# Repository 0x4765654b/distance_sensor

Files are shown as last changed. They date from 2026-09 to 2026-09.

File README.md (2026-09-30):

# SaltMon — Water-Softener Salt Level Monitor

SaltMon watches the salt tank of a Culligan Gold Series water softener. A US-100 ultrasonic sensor, mounted under
the tank lid, measures the distance down to the salt. An ESP32-C6 in a wall-mounted box turns that distance into a
salt level. It shows the level on lid LEDs and publishes readings to AWS IoT Core. A SaltMon AWS stack stores the
history, forecasts when the salt will run out, and publishes the results over SNS. There, the ChoreCore household
app picks them up and creates an "Add salt" chore.

**Status:** design phase. The requirements, the carrier schematic and the routed carrier PCB are done. Firmware,
the cloud stack and the tooling are not started yet.

## Repository Layout

```
docs/                     requirements, pin map, integration contract, pick list, datasheets
kicad/lib/                ESP32-C6-DevKitM-1 symbol + socketed footprint (generated)
kicad/DepthSensor/        carrier PCB project (KiCad 10): schematic, board, Gerbers, generator scripts
models/                   ESP32-S3 dev-kit library (not used; kept for reference)
firmware/                 ESP-IDF application                      (planned)
cloud/                    SaltMon-<env> CDK stack + Lambdas        (planned)
tools/                    provision.py, saltmon-config.py          (planned)
```

## Documents

| Document | Contents |
|---|---|
| [docs/requirements.md](docs/requirements.md) | System requirements: design decisions, parts, power, LEDs, sensor, firmware, cloud, mechanics, verification |
| [docs/pinmap.md](docs/pinmap.md) | Kit header pads, carrier connectors, U2 pinout. Source of truth for firmware `board.h` |
| [docs/integration-contract.md](docs/integration-contract.md) | SNS message contract between SaltMon and its consumers (ChoreCore) |
| [docs/pick-list.md](docs/pick-list.md) | Everything to buy or gather for one build (carrier, cables, enclosure) |
| [docs/lid-pick-list.md](docs/lid-pick-list.md) | The lid panel board: parts, LED spacers, mounting hardware, assembly order |

## Hardware

- **Carrier PCB:** 80.5 × 92 mm, 2-layer, all through-hole. The ESP32-C6-DevKitM-1 plugs into female headers.
  The board also carries a TBD62783APG LED driver, the power path (fuse, lid switch loop, Schottky diode), the
  sensor-line filters, and keyed headers for the lid ribbon (J_PANEL) and the sensor ribbon (J_SNS).
- **Lid panel PCB:** 50 × 63 mm, passive, on standoffs behind the lid. It holds 8 flat-top LEDs (salt level,
  network, activity, power) and pads for the panel-mounted on/off slide switch and push-button. A 16-way ribbon
  with an IDC socket at each end connects it 1:1 to the carrier. The same KiCad file carries the 1:1 lid drilling
  template on User.Drawings. What each LED shows is in requirements §5.4.
- **Sensor:** a US-100 in UART mode on a 6-way ribbon, about 1.2 m long.
- **Enclosure:** a gasketed ABS junction box, wall-mounted through its 4 corner holes.

Gerbers for fabrication are in `kicad/DepthSensor/depth_gerber/` (also zipped as `depth_gerber.zip`).

### Regenerating the Schematic and PCB

The schematic, the kit footprint and the PCB are all generated by scripts. Change the script, not the KiCad file,
then regenerate:

```sh
KICAD=/Applications/KiCad/KiCad.app/Contents
KPY=$KICAD/Frameworks/Python.framework/Versions/Current/bin/python3   # KiCad's Python (has pcbnew)
CLI=$KICAD/MacOS/kicad-cli

python3 kicad/lib/gen_devkit.py                    # kit symbol + footprint
python3 kicad/DepthSensor/gen_schematic.py         # schematic (deterministic UUIDs)
$CLI sch erc kicad/DepthSensor/DepthSensor.kicad_sch

$KPY kicad/DepthSensor/gen_pcb.py                  # place, autoroute (Freerouting), pour GND
$KPY kicad/DepthSensor/gen_pcb.py --no-route       # placement only
$CLI pcb drc --schematic-parity kicad/DepthSensor/DepthSensor.kicad_pcb

python3 kicad/LidPanel/gen_schematic.py           # lid panel: same steps
$KPY kicad/LidPanel/gen_pcb.py
$CLI pcb drc --schematic-parity kicad/LidPanel/LidPanel.kicad_pcb
$CLI pcb export pdf --mode-single -l User.Drawings --scale 1 -o lid-template.pdf kicad/LidPanel/LidPanel.kicad_pcb
```

Helpers shared by both boards are in `kicad/lib/schgen.py` (schematic) and `kicad/lib/pcbgen.py` (PCB).

`gen_pcb.py` needs Java 21+ and the Freerouting jar at `kicad/freerouting/freerouting-*.jar`. The jar is not in git;
download it from the [Freerouting releases](https://github.com/freerouting/freerouting/releases). It was tested
with 2.4.1. Close the board in KiCad before regenerating, and re-export the Gerbers afterwards.

## License

[MIT](LICENSE)

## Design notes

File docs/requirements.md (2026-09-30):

# Salt Level Monitor — System Requirements

Status: **DRAFT v0.8** (2026-09-30) — design phase. Covers the hardware (carrier PCB + passive lid panel PCB), device firmware, the `SaltMon` AWS stack, and the ChoreCore consumer contract. Open items are in [§12](#12-open-questions).

Reference docs in `docs/`:
- `4019_Web.pdf` — Adafruit US-100
- `esp32-c6-devkitm-1-schematics.pdf`, `-dimensions.pdf`, `-dimensions.dxf` — ESP32-C6-DevKitM-1 v1.0
- Culligan Gold Series Owner's Guide (P/N 01018854): <https://www.culligan.com/wp-content/uploads/2019/07pdf/Gold_Softener_01018854.pdf>
- `esp-dev-kits-en-master-esp32s3.pdf`, `models/ESP32_S3_DEVKITM_1_N8/` — **not used** (D-02)

### Proposed repository layout

```
docs/       requirements, pin map, ICDs, datasheets
kicad/      DepthSensor carrier PCB (KiCad 10)
firmware/   ESP-IDF v5.x application
cloud/      SaltMon-<env> CDK stack (TypeScript) + Python Lambdas
tools/      provision.py, saltmon-config.py
```

The ChoreCore consumer feature lives in `~/github/chorecore` (§8.7).

---

## 1. Product Summary

A monitor for the salt tank of a **Culligan Gold Series (9" media tank)** water softener.
A US-100 ultrasonic sensor mounted **on the underside of the salt tank lid** looks down at
the salt. It connects over a ribbon cable to a **wall-mounted enclosure** nearby. The enclosure
holds an ESP32-C6, which works out the salt level, shows it on the lid LEDs, and publishes
readings to **AWS IoT Core**. A **SaltMon** AWS stack in this repo stores the history, forecasts
when salt will run out, and publishes the results. The **ChoreCore** household app consumes them and creates an "Add salt" chore when it is time.

### 1.1 Salt Tank & Installation Geometry

From the Culligan Gold Series specification: the user's **375 lb** salt tank is **18 in dia × 43 in** (45.7 × 109 cm). It has a salt support plate, a Dubl-Safe brine valve inside a brine chamber tube at the side of the tank, and water kept about 1 in above the support plate. Culligan says to fill salt "to within a few inches of the top".

```
     wall-mounted enclosure                    salt tank lid (removable for refills)
   ┌───────────────────┐                  ┌───────────────────────────────┐
   │ LEDs, switch, btn │   ribbon cable   │  ▼▼ US-100 on underside       │
   │  (front panel)    │══════════════════╪══╝  offset away from brine    │
   │  [carrier + ESP32]│  (~1.2 m, slack  │      chamber                  │
   └───┬───┬───┬───────┘   for lid lift)  │                               │
      jack USB cable                      │   d ≈ 8–15 cm   salt, full    │ ║ brine
                                          │                               │ ║ chamber
                                          │   15° beam                    │ ║ tube
                                          │   d_low         refill point  │ ║
                                          │   ~~~ water ~1 in above plate │ ║
                                          │ ═══ salt support plate ═══    │ ║
                                          └───────────────────────────────┘
                                             109 cm (43 in) tall, 45.7 cm dia
```

| ID | Requirement |
|---|---|
| GEO-01 | Measurement range 5–110 cm. The US-100 is specified for 2–450 cm (best 10–250 cm). Accuracy ±(0.3 cm + 1%). |
| GEO-02 | Mount the sensor on the lid underside with the transducers pointing straight down, **3–5 cm off the tank center, on the side away from the brine chamber**. The beam footprint radius is about 0.13 × depth (≈ 14 cm at the plate). The tank radius is 22.9 cm, so the brine-chamber tube and the walls stay out of the beam down to the plate. |
| GEO-03 | Readings < 50 mm → `OBSTRUCTED` (salt piled against the sensor, or the lid is off and something is in front of it). |
| GEO-04 | The salt support plate is **1 in (25 mm) above the tank floor**, and the water sits about 1 in above the plate. Measured from the lid underside (≈ tank top, 1092 mm), that puts the plate at about 1067 mm and the water at about 1041 mm. Defaults until calibrated: `d_full` = 150 mm (salt a few inches below the top), **`d_low` = 900 mm** (salt ≈ 5½ in above the water ≈ 55 lb left, enough for a few regenerations). At install, record the real `d_plate` with the tank low and set `d_low` = `d_plate` − 170 mm. |
| GEO-05 | **Salt mass estimate (cloud):** 18 in dia → 254 in² of cross-section. At a salt bulk density of about 70 lb/ft³ (configurable), that is about **10.3 lb per inch** of salt height (≈ 4.1 lb/cm). A 40 lb bag raises the level by about 4 in. |
| GEO-06 | The lid is lifted at every refill. The cable needs enough slack and strain relief at both ends, and it unplugs at the sensor end. |

### 1.2 System Block Diagram

```
 ┌──────────────────────────── Carrier PCB (enclosure floor) ─────────────────────────────┐
 │ J1 jack ─► F1 PTC ─► (J_PANEL: lid switch)  ─► D1 Schottky ─► V_SYS ~4.6 V             │
 │                                                                  │                      │
 │  ESP32-C6-DevKitM-1 (socketed) ◄── 5V pin ───────────────────────┤                      │
 │     3V3 ─────────────────────────────────► J_SNS (2×3 IDC) ══ ribbon ══► US-100 (lid)   │
 │     GPIO22/23 UART1 ─── 100 Ω ───────────► J_SNS                                        │
 │     GPIO ×8 ─► U2 TBD62783APG ─► R ×8 ───► J_PANEL (2×8 IDC)                            │
 │     GPIO19 ◄── button ───────────────────── J_PANEL                                     │
 │  V_SYS ─► R_PWR ─────────────────────────► J_PANEL                                      │
 └────────────────────────────────────────────────────╥────────────────────────────────────┘
                                                      ║ 16-way IDC ribbon, ~20 cm, IDC socket each end, 1:1
 ┌──────────── Lid panel PCB (behind the lid) ────────╨───────────┐
 │  8 × 5 mm flat-top LEDs · pads for panel switch + push-button  │
 └────────────────────────────────────────────────────────────────┘
       Wi-Fi 2.4 GHz ─► router ─► AWS IoT Core ─► SaltMon stack (ingest · history · forecast) ─► SNS ─► ChoreCore (chore · reminders · UI)
```

---

## 2. Design Decisions Log

| ID | Decision | Rationale |
|---|---|---|
| D-01 | Monitor the salt level for a Culligan Gold Series (9") softener. | User |
| D-02 | ESP32-C6-DevKitM-1. | User |
| D-03 | Barrel jack on the carrier PCB. Power switch on the housing. | User |
| D-04 | All through-hole parts. Dev kit and US-100 are removable (they plug into headers). | User |
| D-05 | The US-100 sits **on the underside of the tank lid, connected by ribbon cable**. The enclosure is **wall-mounted** nearby. | User. The enclosure no longer has to sit on the tank. |
| D-06 | Enclosure: user's unlabeled **ABS gasketed junction box**, about 4.5 × 3.5 × 2 in (≈ 115 × 90 × 55 mm class). It has a deep base, a tray-style lid, brass inserts at the corners, and PCB bosses in the floor (§9). The RadioShack 270-1801 is rejected. | Fits the carrier + kit + lid wiring with margin. The gasket helps in a humid utility room. |
| D-07 | LED driver: TBD62783APG (8-ch source driver). All cathodes go to GND. | Through-hole; 3.3 V inputs; suits the common-cathode bi-color LED. |
| D-08 | White power LED is hard-wired to V_SYS. | "Power stays on dimly" |
| D-09 | Separate indicators for network status (bi-color), network activity (Blue), and sensor activity (Purple). | User |
| D-10 | **Lid panel PCB** (`kicad/LidPanel`, 50 × 63 mm, passive) on standoffs behind the lid. It holds the 8 flat-top LEDs, solder pads for the panel-mounted switch and button, and J_LID, a right-angle 2×8 shrouded header wired 1:1 to J_PANEL. The resistors, driver and pull-up stay on the carrier. The switch and button stay panel-mounted so the lid seals. | Replaces the hand-wired lid (v0.7): no fanned-out ribbon, no GND bus wire, and the board doubles as a drilling jig. The lid still unplugs from the carrier with one connector. |
| D-11 | Power switch = user's panel-mount SPDT mini slide switch (**2 A, 125 V AC**), used as SPST (common + one throw). F1 = **0.75 A hold**. | 2 A is about 4× the 480 mA peak. The 0.75 A fuse protects the 28 AWG ribbon conductors in the switch loop. |
| D-12 | Sensor cable = 6-way 0.05" flat ribbon, **keyed 2×3 IDC** at the carrier and a 1×5 2.54 mm Dupont housing at the sensor. | The keyed carrier end can't be plugged in backwards. The sensor end plugs onto the US-100's own header. |
| D-13 | Reverse-polarity protection is a series Schottky diode. | Also blocks backfeed from the kit's 5V/USB supply. |
| D-14 | US-100 runs in UART mode at 3.3 V. | Simple, temperature-compensated, direct logic levels. |
| D-15 | Device ↔ cloud via AWS IoT Core MQTT/TLS, one X.509 certificate per device. Firmware on ESP-IDF v5.x. | User's AWS stack |
| D-16 | **Two stacks.** `SaltMon-<env>` (this repo) owns IoT, history, and the forecast, and publishes records to SNS. `ChoreCore-<env>` adds a consumer feature that turns them into chores and UI. They are coupled only by the SNS contract (§8.3) through SSM. Account 345482189436 / us-east-1. | User. The device side stays reusable, and ChoreCore stays free of IoT concerns. |
| D-19 | The "Add salt" chore is **forecast-driven** (days to refill ≤ 3 based on history), with REFILL state as the fallback. It is assigned to Jeff Harman. | User |
| D-17 | The device computes level and alerts locally. It also publishes raw burst statistics. | LEDs keep working offline; the cloud can recompute from the raw data. |
| D-18 | USB-C (UART port) reachable **with the lid on** through a cut-out in the enclosure wall. | User |

---

## 3. Components

### 3.1 Carrier PCB

| Ref | Part | Package | Notes |
|---|---|---|---|
| U1 | ESP32-C6-DevKitM-1 | 2 × 1×15 female headers, rows **22.86 mm** apart | 25.4 × 48.26 mm; antenna overhangs 5.37 mm; 4 MB flash |
| U2 | TBD62783APG | DIP-18 in a socket | VIN(ON) ≥ 2.0 V |
| J1 | 5.5 × 2.1 mm DC jack (e.g. CUI PJ-102AH) | THT | Center-positive, at the bottom board edge |
| F1 | PTC, **0.75 A hold / 1.5 A trip** (e.g. Littelfuse RXEF075) | Radial | |
| D1 | 1N5822 Schottky | DO-201AD | |
| D2 | P6KE6.8A TVS (optional) | DO-15 | |
| C1 | 220 µF 16 V | Radial | V_SYS bulk |
| C2–C5 | 100 nF | Radial | Decoupling |
| C6 | 10 µF | Radial | At J_SNS VCC |
| C7, C8 | 1 nF | Radial | Sensor TX/RX filter to GND (RC = 100 ns with 100 Ω; a 9600-baud bit is 104 µs) |
| R | 1/4 W film | Axial | LED current, series, pull resistors |
| RN1 | 8 × 100 kΩ bussed network (common to GND) | SIP-9 | U2 input pull-downs (LED-02) |
| TP1–TP6 | Test pads: V_SYS, 3V3, GND, SNS_TX_C, SNS_RX_C, SW_A | THT pad | |
| J_SNS | 2×3 **shrouded (keyed)** box header, 2.54 mm | THT | Sensor ribbon |
| J_PANEL | 2×8 **shrouded (keyed)** box header, 2.54 mm | THT | Lid wiring ribbon |
| J_SPARE | 1×4 male header (3V3, GND, GPIO20, GPIO21) | THT | |

### 3.2 Lid Panel Parts (`kicad/LidPanel`)

| Ref | Part | Notes |
|---|---|---|
| D1–D8 | 5 mm **flat-top** LEDs: D1 Green, D2 Yellow, D3 Orange, D4 Red, D5 Blue, D6 Purple, D7 Bi-color R/G (3-lead common cathode, assumed pin order R / K / G: check the part), D8 White | Soldered to the lid board on 10 mm nylon LED spacers. The body goes through a Ø5.0 mm lid hole and the flange stops against the inside of the lid (no bezels). **The current resistors stay on the carrier.** |
| J1 (J_LID) | 2×8 shrouded box header, 2.54 mm, **right-angle** | On the back of the board; the ribbon leaves toward the top wall. |
| SW1 | User's SPDT mini slide switch, panel mount, 2 A / 125 V AC | Rectangular slot in the lid plus 2 screw holes (measure the part). Common pin and one throw pin wired to board pads J2 (SW_A, SW_B). |
| SW2 | Momentary panel push-button, normally open, 7 mm or 12 mm threaded bushing (e.g. PBS-110 / 16 mm "R13-507" class) | To be purchased. Wired to board pads J3 (BTN, GND). |
| H1–H4 | M3 mounting holes, 43 × 56 mm pitch | MEC-09 |

### 3.3 Cables

| Cable | Construction |
|---|---|
| Sensor | 6-way 0.05" flat ribbon, 28 AWG, **~1.2 m** (0.6 m run + slack so the lid can be lifted and set aside). Carrier end: 2×3 IDC socket. Sensor end: conductors 1–5 crimped into a 1×5 Dupont female housing (VCC, TX, RX, GND, GND); conductor 6 not used. Pin-1 stripe = VCC. Strain relief at both ends. |
| Lid | 16-way 0.05" flat ribbon, ~20 cm (enough to open the lid and lay it beside the box). A 2×8 IDC socket at **each end**, crimped 1:1 with the pin-1 stripe at the pin-1 mark of both sockets (J_PANEL pin *n* = J_LID pin *n*). |

---

## 4. Power Requirements

| ID | Requirement |
|---|---|
| PWR-01 | Input 5 V DC ±5% on a 5.5 × 2.1 mm center-positive jack. Adapter ≥ 1 A. |
| PWR-02 | Power path: J1 → F1 → J_PANEL (SW_A) → lid SW1 → J_PANEL (SW_B) → D1 → V_SYS. SW_A and SW_B each use **two** ribbon conductors. |
| PWR-03 | Reverse polarity: D1 blocks it. |
| PWR-04 | Overcurrent: F1 (0.75 A hold) trips on a V_SYS short, or on a short in the panel or sensor harness. |
| PWR-05 | Unplugging the lid ribbon opens the power path, so the device is OFF. This is a safe failure. For bench work without the lid, plug in a J_PANEL jumper plug (pins 11–14 shorted). |
| PWR-06 | USB and the jack may be connected at the same time (the kit has 1N5819 diodes on VBUS, and D1 blocks the reverse direction). With SW1 OFF and USB connected, the board runs from USB. |
| PWR-07 | 3V3 (from the kit LDO) powers the ESP32 and the US-100 only. |
| PWR-08 | Wi-Fi stays connected; modem-sleep is allowed. |

### 4.1 Power Budget (V_SYS)

| Load | Typical | Peak |
|---|---|---|
| ESP32-C6, Wi-Fi connected | 25–40 mA | ~350 mA |
| Kit overhead | 15 mA | 60 mA |
| US-100 | 2 mA | 10 mA |
| LEDs (power + dim level + dim net status) | ~3 mA | ~55 mA (self-test) |
| **Total** | **~60 mA** | **~480 mA** |

---

## 5. LED & Lid Panel Requirements

### 5.1 Electrical

| ID | Requirement |
|---|---|
| LED-01 | U2 VCC = V_SYS. The GPIO drive U2 IN1–8. The outputs go through current resistors **on the carrier**, then through J_PANEL to the LED anodes. The LED cathodes go to GND. |
| LED-02 | GPIO HIGH = LED on. Each U2 input has a 100 kΩ pull-down, so all driven LEDs stay off during reset and boot. |
| LED-03 | LEDC PWM on CH1–4 and CH7–8 (the C6's 6 LEDC channels). CH5–6 are plain GPIO outputs. PWM ≥ 1 kHz, ≥ 8-bit. |
| LED-04 | The White power LED is fed from V_SYS through R_PWR on the carrier (1.5 kΩ, about 1 mA). |

| Ch | LED | R | I | Drive | GPIO |
|---|---|---|---|---|---|
| CH1 | Green — level FULL | 180 Ω | 7.8 mA | LEDC0 | GPIO2 |
| CH2 | Yellow — level MID | 300 Ω | 8 mA | LEDC1 | GPIO3 |
| CH3 | Orange — level LOW-ish | 300 Ω | 8 mA | LEDC2 | GPIO0 |
| CH4 | Red — REFILL | 300 Ω | 8 mA | LEDC3 | GPIO1 |
| CH5 | Blue — network activity | 470 Ω | 3 mA | GPIO | GPIO6 |
| CH6 | Purple — sensor activity | 470 Ω | 3 mA | GPIO | GPIO7 |
| CH7 | Bi-color Green — network status | 180 Ω | 7.8 mA | LEDC4 | GPIO14 |
| CH8 | Bi-color Red — network status | 300 Ω | 8 mA | LEDC5 | GPIO18 |
| PWR | White — power | 1.5 kΩ | ~1 mA | hard-wired | — |

### 5.2 J_PANEL Pinout (2×8, 16-way ribbon)

| Pin | Signal | Pin | Signal |
|---|---|---|---|
| 1 | CH1 Green | 2 | CH2 Yellow |
| 3 | CH3 Orange | 4 | CH4 Red |
| 5 | CH5 Blue | 6 | CH6 Purple |
| 7 | CH7 Bi-Green | 8 | CH8 Bi-Red |
| 9 | PWR LED (via R_PWR) | 10 | BTN (to GPIO19; pull-up is on the carrier) |
| 11 | SW_A (from F1) | 12 | SW_A |
| 13 | SW_B (to D1) | 14 | SW_B |
| 15 | GND | 16 | GND |

### 5.3 Lid Layout (lid = front face when wall-mounted; drilling template: MEC-06)

```
   Viewed from outside, portrait, bottom wall down. mm from the lid's inside top-left corner.
   ┌──────────── 82.6 ────────────┐
   │                              │
   │    x 26.3         x 56.3     │
   │    ● FULL         ● PWR      │  y 35
   │    ● MID          ● NET      │  y 46
   │    ● LOW          ● DATA     │  y 57
   │    ● REFILL       ● SENS     │  y 68
   │                              │
   │    [ON|OFF]        (BTN)     │  y 88   (x 30, x 52)
   │                              │
   └──────────────────────────────┘ 108
```

### 5.4 Indicator Behavior

| Indicator | LED | Pattern |
|---|---|---|
| Power | White | Steady and dim whenever V_SYS is present (hard-wired) |
| Salt level | G / Y / O / R | One LED steady and dim for the current band (≥ 75 / 40–75 / 15–40 / < 15 %). **REFILL:** Red blinks at 1 Hz, bright. **Bridge suspected:** the current LED double-blinks every 5 s. **Uncalibrated / obstructed:** a G→R chase every 10 s. **Sensor fault:** level LEDs off |
| Network status | Bi-color | Green steady (dim) = connected to AWS IoT · Amber = Wi-Fi only · Red 1 Hz = no Wi-Fi · Red 4 Hz = TLS/authentication failure · R/G alternating 2 Hz = BLE provisioning |
| Network activity | Blue | 50 ms flash on each acknowledged publish or received message |
| Sensor activity | Purple | 30 ms flash on each reading. 4 Hz continuous = sensor fault |
| Self-test | CH1–8 | Each lights for 200 ms at boot |

---

## 6. Sensor, MCU & I/O Requirements

| ID | Requirement |
|---|---|
| SNS-01 | US-100 in UART mode (rear jumper fitted), 9600 baud 8N1, 3V3 supply. |
| SNS-02 | Connection via J_SNS (2×3 keyed IDC): 1 = 3V3, 2 = SNS_TX (ESP→US-100 Echo/RX), 3 = SNS_RX (US-100 Trig/TX→ESP), 4 = GND, 5 = GND, 6 = NC. |
| SNS-03 | 100 Ω series resistors plus 1 nF to GND on both data lines at J_SNS. 10 µF + 100 nF across 3V3 at J_SNS. |
| SNS-04 | The sensor is mounted on the lid underside with nylon M2 hardware, or in a small bracket through its mounting holes. Transducers pointing straight down (GEO-02). |
| SNS-05 | **Brine-tank air is humid and salty.** Conformal-coat the rear of the US-100 PCB (not the transducers). Put dielectric grease on the Dupont contacts. Treat the sensor as a replaceable part and keep a spare. |
| MCU-01 | The dev kit sits in female headers **with its USB-C ports facing the bottom wall of the enclosure**. There is a cut-out for the UART USB-C port (D-18). The antenna end therefore points up, into the enclosure. |
| MCU-02 | **Antenna keep-out:** no copper on either layer, no connectors or ribbons, within 15 mm of the module antenna. Put a **routed cut-out** in the carrier under the antenna overhang. The enclosure lid is plastic. |
| MCU-03 | Pins to avoid: GPIO4, 5, 8, 9, 15 (strapping; 8 = RGB LED, 9 = BOOT), 12/13 (USB), 16/17 (UART0). |
| MCU-04 | Test points: V_IN, V_SYS, 3V3, GND, SNS_TX, SNS_RX. |

### 6.1 Pin Map

| Signal | GPIO | Kit pin |
|---|---|---|
| CH1–CH4 | 2, 3, 0, 1 | J1-3, J1-4, J1-7, J1-8 |
| CH5, CH6 | 6, 7 | J1-10, J1-11 |
| CH7, CH8 | 14, 18 | J1-12, J3-9 |
| Button | 19 | J3-8 |
| UART1 TX / RX | 22 / 23 | J3-5 / J3-4 |
| Spare | 20, 21 | J3-7, J3-6 |

---

## 7. Firmware Requirements

### 7.1 Platform

| ID | Requirement |
|---|---|
| FW-01 | ESP-IDF v5.x. FreeRTOS tasks: sensor, level/state, LED, network, button. |
| FW-02 | Partitions (4 MB): `nvs`, `nvs_keys`, `esp_secure_cert`, `otadata`, `phy_init`, `ota_0` / `ota_1` (~1.9 MB each). |
| FW-03 | Task watchdog and brownout detector enabled. Reset reason published at boot. |

### 7.2 Measurement & Level

| ID | Requirement |
|---|---|
| FW-10 | Every `sample_interval_s` (default 600 s), run a burst of 15 readings 100 ms apart. A reading of 0 or > 4500 mm is invalid. A burst is invalid if fewer than 8 readings are valid. |
| FW-11 | For each burst, record median, min, max, and valid count, plus the temperature (0x50 → value − 45 °C). |
| FW-12 | Level is the median of the last 6 bursts (1 h). `level_pct = (d_low − d)/(d_low − d_full)`, clamped to 0–100. |
| FW-13 | REFILL is set when the level stays below `refill_pct` (15%) for 3 consecutive hours. It clears only when a refill is detected (≥ 20-point rise within 1 h). |
| FW-14 | A detected refill publishes an event. If the new top is more than 5 cm from `d_full`, prompt re-calibration. |
| FW-15 | Salt-bridge hint: the level stays within ±1 cm for ≥ `bridge_days` (14). |
| FW-16 | Sensor fault: no valid burst for 30 min. OBSTRUCTED: median < 50 mm. |
| FW-17 | Lid-lift handling: a sudden jump to OBSTRUCTED or an implausible reading during a refill is **not** treated as a fault until it has lasted 30 min. |

### 7.3 Button

| Press | Action |
|---|---|
| < 1 s | All indicators bright for 30 s, then an immediate burst and publish |
| Hold 3 s | "Just refilled": set `d_full` from the current reading |
| Hold 10 s | BLE Wi-Fi provisioning mode (10 min) |
| Hold 20 s | Factory reset (Wi-Fi credentials and calibration). The AWS certificate is kept |

### 7.4 Connectivity (device side)

| ID | Requirement |
|---|---|
| CLD-01 | Connect to the AWS IoT ATS endpoint on port 8883 using MQTT 3.1.1 over TLS 1.2 with mutual X.509 authentication. Amazon Root CA 1 is embedded in the firmware. |
| CLD-02 | Thing name `saltmon-<MAC[3..5]>`. The client ID is the same as the thing name. The IoT endpoint and thing name are read from factory NVS (§8.4). |
| CLD-03 | Use `esp-aws-iot` (coreMQTT plus the Device Shadow library, and the Jobs library for v1.1 OTA). |
| CLD-04 | Keep-alive 60 s. Reconnect back-off 1 s → 5 min with jitter. |
| CLD-05 | Sync time with SNTP before TLS, and every 6 h after that. Timestamps are UTC epoch ms. |
| CLD-06 | Offline buffer of 144 records (24 h) in RAM, replayed in order after reconnecting. |
| CLD-07 | QoS 1 publishes. JSON payloads ≤ 512 B. |

---

## 8. Cloud Requirements — Two Stacks

| Stack | Repo | Role |
|---|---|---|
| **`SaltMon-<env>`** (producer) | this repo, `cloud/` | The device side of AWS IoT Core. It registers devices, applies the policy, ingests and validates readings, and keeps the system-of-record history. It computes the forecast and detects offline devices. It **publishes normalized records** on an SNS topic. |
| **`ChoreCore-<env>`** (consumer) | `~/github/chorecore` (new feature) | Subscribes to the SaltMon topic, maps devices to a family, creates the "Add salt" and "Check salt monitor" chores, and shows the level in the UI. It does not need to know about MQTT, certificates, or IoT. |

Both stacks live in account `345482189436` (profile `sandbox26`), region **us-east-1**. The environment is `dev` unless stated otherwise. The only coupling is the **integration contract** (§8.3): one SNS topic ARN, published in SSM Parameter Store, plus a message schema. There are no CloudFormation exports, so either stack can be updated or redeployed on its own.

```
 ESP32 ──MQTT/TLS──► IoT Core ──rule──► λ saltmon-ingest ──► DDB SaltMon-<env>-readings
                                           │ (validate, dedupe)
                                           ▼
 λ saltmon-forecast (hourly) ──────► SNS SaltMon-<env>-readings ──► SQS (+DLQ) ──► ChoreCore λ softener
 λ saltmon-watchdog (15 min) ──────►     (kind = telemetry | event |                  ├─► table (SALTREAD#, SOFTENER#)
                                          forecast | status)                          ├─► "Add salt" chore ─► reminders
                                                                                      └─► GET /softener ─► UI
```

### 8.1 Device ↔ IoT Interface (MQTT)

| Direction | Topic | Payload |
|---|---|---|
| Device → cloud | `dt/saltmon/{thing}/telemetry` | Every burst (below) |
| Device → cloud | `dt/saltmon/{thing}/event` | `boot`, `state_change`, `refill_detected`, `bridge_suspected`, `sensor_fault` |
| Both | `$aws/things/{thing}/shadow/name/config/#` | Config shadow (§8.5) |
| Cloud → device (v1.1) | `$aws/things/{thing}/jobs/#` | OTA |

Telemetry (schema v1):

```json
{ "schema":1, "thing":"saltmon-a1b2c3", "ts":1790000000000, "seq":1234,
  "distance_mm":612, "distance_min_mm":598, "distance_max_mm":640, "valid":14, "samples":15,
  "level_pct":62.5, "state":"OK", "bridge_suspected":false,
  "temp_c":18, "rssi_dbm":-61, "uptime_s":86400, "fw":"0.1.0" }
```

`state` ∈ `OK | REFILL | FAULT | OBSTRUCTED | UNCALIBRATED`

Event: `{ "schema":1, "thing", "ts", "seq", "type", "from", "to", "detail" }`. The `boot` event adds `reset_reason` and `fw`.

The device knows nothing about families or ChoreCore.

### 8.2 SaltMon Stack Requirements (this repo, `cloud/`)

| ID | Requirement |
|---|---|
| IOT-01 | **IaC:** AWS CDK v2 in TypeScript (matching ChoreCore) under `cloud/`. Lambdas are Python 3.13 on arm64 with Powertools (logger, metrics, tracer). cdk-nag `AwsSolutionsChecks` is on. Everything is tagged `Project=SaltMon`. Stack name `SaltMon-<env>`, deployed with `cloud/deploy.sh <env>` (`AWS_PROFILE=sandbox26 AWS_REGION=us-east-1`). |
| IOT-02 | **Registry:** thing type `SaltMonitor`, and one IoT policy `SaltMon-<env>-device` scoped by policy variables. `iot:Connect` only with client ID `${iot:Connection.Thing.ThingName}`, and only if the thing is attached (`iot:Connection.Thing.IsAttached`). Publish only to `dt/saltmon/${iot:Connection.Thing.ThingName}/*`. Access only its own `config` shadow and jobs topics. Things and certificates are created by the provisioning tool (§8.4), not by CDK. |
| IOT-03 | **Ingest:** topic rule `saltmon_<env>_ingest`: `SELECT *, topic(3) AS thing_topic, topic(4) AS kind, timestamp() AS received_at FROM 'dt/saltmon/+/+'` → Lambda `saltmon-ingest`. Error action to a CloudWatch Logs group. |
| IOT-04 | **`saltmon-ingest`** does four things: <br>• Rejects records where `thing` ≠ `thing_topic` or `schema` is unknown (logs and counts them). <br>• Clamps and validates fields. <br>• Writes the record **conditionally** (`attribute_not_exists`), so duplicates from QoS 1 or the offline replay are dropped. <br>• Publishes **only newly stored** records to the SNS topic as §8.3 envelopes. |
| IOT-05 | **Readings table** `SaltMon-<env>-readings`: PK `thing`, SK `<kind>#<ts>` (`T#`, `E#`, `F#`, `S#`), plus an item `STATE` holding lastSeen, last level/state, fw, and online flag. On-demand billing, PITR on, **`RemovalPolicy.RETAIN`**, deletion protection on, TTL of 2 years on T#/E#/F#. |
| IOT-06 | **`saltmon-forecast`** (EventBridge Scheduler, hourly): per thing, take the hourly medians of the last 14 days. Cut the series at the last refill (a rise of ≥ 20 points). Fit a least-squares line on ≥ 48 h of data and compute: <br>• consumption rate (in/day, and lb/day at 10.3 lb/in — GEO-05) <br>• `refill_eta` (when the line crosses `refill_pct`) <br>• `days_to_refill` <br>• a confidence score (R² and sample count). <br>Store the result as `F#` and publish `kind=forecast`. If there is too little history, publish `confidence:"insufficient"` and no ETA. |
| IOT-07 | **`saltmon-watchdog`** (every 15 min): if no telemetry for > **1 h**, mark the thing offline and publish `kind=status {online:false, last_seen}`. On the next record, `saltmon-ingest` publishes `online:true`. Only transitions are published. |
| IOT-08 | **Topic** `SaltMon-<env>-readings`: standard SNS, SSE with a customer-managed KMS key whose key policy allows the SaltMon Lambdas to publish and SNS to deliver to subscriber queues in this account. The topic policy allows `sns:Subscribe` only from account `345482189436`. Its ARN is published to **SSM `/saltmon/<env>/readings-topic-arn`**, and the schema version to `/saltmon/<env>/contract-version`. |
| IOT-09 | **Config tool** `tools/saltmon-config.py`: shows the shadow, sets `desired` keys (§8.5), and runs "calibrate full/low from the latest reading". This is the only v1 remote-config path. ChoreCore is read-only toward the device in v1. |
| IOT-10 | **Observability:** Powertools metrics `Ingested`, `Duplicate`, `Rejected`, `PublishFailed`. The rule error log group, and all Lambda logs, are kept for 30 days. |
| IOT-11 | **Security:** no AWS credentials on the device. Each Lambda role is least-privilege: the table, `sns:Publish` on this topic only, and KMS on this key only. No public endpoints. |
| IOT-12 | **Tests:** pytest with moto for ingest (validation, dedupe, publish only when new), forecast (synthetic consumption series, refill cut, insufficient data), and watchdog transitions. CDK Jest assertions cover the policy document, rule SQL, and RETAIN/PITR. |
| IOT-13 | **Cost:** 1 device, about 150 messages/day, hourly forecast: **< $1/month**. |
| IOT-14 | **Deploy safety:** `cdk diff` is reviewed before every deploy, and I **ask before running `cdk deploy`**. No stateful resource is ever replaced. `cdk destroy` leaves the table and KMS key (RETAIN). |

### 8.3 Integration Contract (SaltMon → consumers)

Every SNS message has message attributes `kind` (String) and `thing` (String), so subscribers can use filter policies. The body is:

```json
{ "contract": 1, "kind": "telemetry|event|forecast|status",
  "thing": "saltmon-a1b2c3", "ts": 1790000000000, "received_at": 1790000000321,
  "data": { ... } }
```

| `kind` | `data` |
|---|---|
| `telemetry` | The device telemetry fields (§8.1) |
| `event` | The device event fields (§8.1) |
| `forecast` | `level_pct, rate_in_per_day, rate_lb_per_day, refill_eta (epoch ms or null), days_to_refill (or null), confidence ("high"\|"low"\|"insufficient"), r2, points` |
| `status` | `online (bool), last_seen` |

Rules:
- Delivery is **at least once** and not ordered. Consumers de-duplicate on (`thing`, `kind`, `ts`).
- Fields are only ever added. A breaking change bumps `contract` and is published side by side on a new topic.
- The contract doc lives at `docs/integration-contract.md`. ChoreCore's intent links to it.

### 8.4 Provisioning Tool (`tools/provision.py`)

| ID | Requirement |
|---|---|
| PRV-01 | Inputs: serial port and env (`dev` by default). It runs with `AWS_PROFILE=sandbox26 AWS_REGION=us-east-1`. It reads the device MAC with `esptool` and derives the thing name `saltmon-<mac3>`. |
| PRV-02 | Steps: <br>1. Create the thing (type `SaltMonitor`). <br>2. `CreateKeysAndCertificate`. <br>3. Attach policy `SaltMon-<env>-device`. <br>4. Attach the cert to the thing. <br>5. Build the `esp_secure_cert` partition (cert, key, Amazon Root CA 1) and a factory NVS partition (ATS endpoint, thing name). <br>6. Flash both. |
| PRV-03 | Idempotent: an existing thing is reused, and a new cert is issued only with `--rotate`. Keys live only in git-ignored `tools/out/` and are wiped after a verified flash, unless `--keep`. |
| PRV-04 | `--dry-run` prints every AWS call without making it. `--revoke` sets the cert INACTIVE and never deletes anything. Deleting a thing or cert needs a separate command plus a typed confirmation. |

### 8.5 Device Shadow `config`

| Key | Default | Range |
|---|---|---|
| `d_full_mm` | 150 | 50–1100 |
| `d_low_mm` | 900 | 100–1100, > `d_full_mm` |
| `refill_pct` | 15 | 5–50 |
| `sample_interval_s` | 600 | 60–3600 |
| `led_dim` | 20 | 1–255 |
| `bridge_days` | 14 | 0–60 (0 = off) |

The device validates each `desired` value, applies it, stores it in NVS, and writes it back to `reported`. It rejects invalid values and returns an error field.

### 8.6 Device Security

| ID | Requirement |
|---|---|
| SEC-01 | Wi-Fi setup via ESP-IDF BLE provisioning (ESP BLE Provisioning app), security scheme 1 or 2. The proof-of-possession code is on a label inside the enclosure. |
| SEC-02 | The certificate and key live in `esp_secure_cert`, written by the provisioning tool (§8.4). They never appear in the firmware image or in git (`.gitignore` covers `*.pem`, `*.key`, `tools/out/`). |
| SEC-03 | NVS encryption is on, using the C6's HMAC-based scheme. |
| SEC-04 | Flash encryption and Secure Boot v2 are an optional release step only (they burn eFuses irreversibly). |
| SEC-05 | TLS or authentication failures never cause a boot loop. The status LED shows Red 4 Hz, and the device retries with back-off. |

### 8.7 ChoreCore Consumer Feature (requirements handed to ChoreCore)

To be written up as an AI-DLC intent in ChoreCore and implemented there, following its AGENTS.md (invariants INV-01…06, the config-driven Lambdas, and tests). Listed here so both sides agree on the contract.

| ID | Requirement |
|---|---|
| CC-01 | **Subscribe:** an SQS queue `ChoreCore-<env>-saltmon` (SSE-SQS, with a DLQ after 5 receives) subscribed to the topic from SSM `/saltmon/<env>/readings-topic-arn`, with raw delivery. The queue triggers Lambda `softener` in batches with partial-batch failure reporting. A new construct `saltmon-consumer-construct.ts`, plus a config block in all four `app-config.*.json`. |
| CC-02 | **Device→family map:** an admin-managed record `SOFTENER#<thing>` under `family_pk()`, seeded from config `saltmon.devices: {"saltmon-xxxxxx": "ct_harman"}`. Messages for unmapped things are logged and dropped. |
| CC-03 | **Store:** `SALTREAD#<thing>#<ts>` records (`ttl` of 1 year) and the latest level, state, forecast and online flag on `SOFTENER#<thing>`. Idempotent on (thing, kind, ts). Numbers stored as `Decimal`. |
| CC-04 | **"Add salt" chore (forecast-driven):** when a `forecast` message has `days_to_refill` ≤ **`lead_days` (default 3)**, confidence ≠ `insufficient`, and there is no open task, create a `due_by` task "Add salt to water softener" (list "Softener", **assigned to Jeff Harman** by Cognito sub from config, `dueAt = refill_eta`, back-reference `softenerAction`). If the task is already open, update its `dueAt` when the ETA moves by more than 12 h. **Fallback:** if a telemetry `state=REFILL` arrives with no open task, create the task due now. Delivery uses the existing `reminders`. |
| CC-05 | **Never auto-complete (INV-01):** `refill_detected` only annotates the open task and enables **Mark done** in the UI. A human completing the task records a refill on `SOFTENER#<thing>`. |
| CC-06 | **"Check salt monitor" chore:** created when `status.online=false` persists for > 1 h after the message (2 h total), or on FAULT/OBSTRUCTED telemetry lasting > 1 h. Assigned to Jeff, one open at a time, never auto-completed. |
| CC-07 | **API and UI:** `GET /softener` and `GET /softener/{thing}/readings`, both Cognito-authorized and family-scoped. `Softener.tsx` shows a level gauge (% and ≈ lb), a 30/90-day chart, days to refill with a confidence note, online/last seen, and a link to the open chore. It is the toggleable section `softener`. It is read-only toward the device in v1. |
| CC-08 | **Tests:** pytest with moto (SQS event → store, chore create/update/no duplicate, unmapped thing, INV-01), CDK Jest, and Vitest. |
| CC-09 | **Deploy order:** SaltMon first, then ChoreCore. The ChoreCore stack reads the SSM parameter at deploy time, so it has no hard CloudFormation dependency. |

---

## 9. Enclosure & Mechanical Requirements

Enclosure: the user's unlabeled ABS gasketed junction box. Measured 2026-09-28 (user sketch):

| Dimension | inch | mm |
|---|---|---|
| Outside L × W | 4½ × 3½ | 114.3 × 88.9 |
| **Inside depth, base** (floor to rim) | 1¾ | 44.5 |
| **Inside depth, lid** | ½ | 12.7 |
| Total inside depth, lid closed | 2¼ | 57.2 |
| Wall thickness | ⅛ | 3.2 |
| **Inside L × W** | **4¼ × 3¼** | **108.0 × 82.6** |
| Corner pillars (each corner, inside) | ¾ across the width × ½ along the length | 19.1 × 12.7 |
| Gap between pillars, across the short wall | 1¾ | 44.5 |
| Gap between pillars, along the long wall | 3¼ | 82.6 |

```
      Carrier outline, inside view (portrait, lid toward viewer), mm
      ┌──┐◄──────────── 82.6 inside ────────────►┌──┐
      │P │                                      │ P│  P = pillar 19.1 × 12.7
      └──┘──────────────────────────────────────└──┘
         │      U2 · J_PANEL · RN1 · R1–R8      │
         │  side   ┌── kit antenna ──┐   side   │   board 92 × 80.5
         │  zone   │  keep-out 15 mm │   zone   │   (bottom tab 14 × 39.5)
         │ (F1, D1,│                 │ (R, C,   │
         │  C1)    │   ESP32-C6 kit  │  J_SNS,  │
      ┌──┐──────┐  │   25.4 × 48.3   │ ┌J_SPARE)└──┐
      │P │      │  └────┤USB├────────┘J1│     │ P│
      └──┘      └───────────────────────┘     └──┘
                ▲ bottom wall: USB-C cut-out + DC jack hole
```

| ID | Requirement |
|---|---|
| MEC-01 | The box is wall-mounted in portrait with the lid facing out (lid = front panel, §5.3). The **bottom wall** (the short wall) carries the DC jack hole and the USB-C cut-out, which exposes the UART port. The **sensor ribbon** leaves through a grommet or slot in the side wall just above the lower pillar, with a drip loop and strain relief (a cable tie through two holes in the carrier). |
| MEC-02 | **Carrier outline 92.0 × 80.5 mm: a full-width body with one 14.0 × 39.5 mm tab at the bottom end** (14.0 × 20.5 mm notches at the two bottom corners, ≈ 1 mm clearance to walls and pillars). The tab fits between the bottom pillars with 2.5 mm clearance per side. The top edge is straight and sits just below the top pillars; the top tab of rev 0.1 held no parts and was removed in rev 0.2. |
| MEC-03 | The bottom tab holds the dev kit (USB end flush with the tab edge, 1 mm from the wall) and J1 beside it. That is 25.4 + 9 mm plus gaps, about 37.5 of the 39.5 mm available. The **antenna end points into the box center**. The antenna keep-out (MCU-02) goes there: a ~26 × 15 mm routed slot under the antenna overhang, and no copper within 15 mm. The full-width body holds U2, the resistors, J_PANEL, J_SNS, F1, D1, and C1. |
| MEC-04 | Stack height from the floor: standoffs 6 mm → carrier 1.6 mm (top at 7.6) → female headers 8.5 mm → kit PCB (top at 17.7) → **USB-C centered about 19.3 mm above the floor**. **DC jack (PJ-102AH) axis about 14.1 mm above the floor.** The tallest carrier part is C1 (8 × 11.5 mm, top at 19.1). Tallest overall is the kit and module at about 21 mm, which leaves about 23 mm in the base plus 12.7 mm in the lid for the lid-mounted parts (the push-button body is ≤ 20 mm deep). The USB-C cut-out is 13 × 8 mm (clears a plug overmold through the 3.2 mm wall), and the jack hole is Ø8 mm. |
| MEC-05 | Mounting: 4 × M3 holes in the full-width region, just inside the notches. The carrier sits on 6 mm nylon standoffs, screwed to the molded floor bosses if they line up, otherwise through M3 holes drilled in the floor with sealing washers. |
| MEC-06 | Lid parts stay inside the gasket line and clear of the four pillar screws. The 1:1 **drilling template** is the User.Drawings layer of `kicad/LidPanel/LidPanel.kicad_pcb` (export command in `kicad/LidPanel/gen_pcb.py`). Print it at 100 %, check the 50 mm bar, and tape it to the outside of the lid. After drilling, seal the switch and button with their own nuts or gaskets and run a bead of silicone around each LED flange on the inside. |
| MEC-07 | The box is mounted through its 4 corner screw holes. There are no wall screws through the base floor in the board area, and the carrier has no screw keep-clear zones. |
| MEC-08 | Carrier and lid PCBs: 2-layer, 1.6 mm, 1 oz copper, all through-hole. GND pour everywhere except the carrier's antenna keep-out. Both pass KiCad ERC and DRC with zero errors. |
| MEC-09 | Lid board mounting: 4 × M3 nylon standoffs, about 10 mm, between the lid and the board front. Fix them to the lid with M3 screws and sealing washers through the template's Ø3.2 holes, or bond them on (no holes). Assembly: (1) mount the bare board; (2) each LED sits on a nylon LED spacer the same length as the standoffs, which pushes its flange against the lid; (3) solder and trim the leads. Parts: `docs/lid-pick-list.md`. J_LID hangs about 9 mm behind the board (bottom about 36 mm above the floor with the lid closed), which clears the carrier and the kit. |

---

## 10. Verification Plan

| Test | Pass | Covers |
|---|---|---|
| −5 V at the jack | No V_SYS, no damage | PWR-03 |
| Short V_SYS | F1 trips and recovers | PWR-04 |
| Unplug the lid ribbon | Device off, nothing damaged | PWR-05 |
| USB only with SW1 off; USB and jack together | Runs; no backfeed | PWR-06 |
| Reset / flash | Only the White LED is lit | LED-02/04 |
| LED currents | Within ±25% of §5.1 | LED-01 |
| 1.2 m sensor ribbon: 1000 bursts | ≥ 99.9% valid frames | SNS-02/03 |
| Bench: 10 / 30 / 60 / 100 cm onto salt in a bucket | Median within ±1.5 cm | FW-10 |
| In the tank, full and near-empty | No echoes from the brine chamber (min ≈ median) | GEO-02 |
| Lift the lid for 5 min during a refill | No fault alert; refill detected afterwards | FW-14/17 |
| First boot with no credentials | BLE provisioning works | SEC-01 |
| Normal run | A `T#` item every 10 min, an SNS message, and a ChoreCore `SALTREAD#` record; the Softener page updates | IOT-04/05, CC-03/07 |
| Publish to another thing's topic | Denied by the policy | IOT-02 |
| Replay the same record twice | Stored once and published once | IOT-04 |
| Feed the forecast a synthetic 1 in/day decline | ETA correct to ±0.5 day; `insufficient` with < 48 h of data | IOT-06 |
| Forecast reports ≤ 3 days | One "Add salt" chore due at the ETA; reminders fire; no duplicate | CC-04 |
| Force REFILL (shadow `d_low_mm` = current distance − 10 mm) with no chore open | Fallback chore due now | CC-04 |
| Refill the tank with the chore open | Chore annotated, **not** completed; the Mark done button works | CC-05 |
| Power off for 2.5 h | `status` offline message, then one "Check salt monitor" chore; online again after power returns | IOT-07, CC-06 |
| Send a message to the ChoreCore queue that fails to process | Lands in the DLQ after 5 receives | CC-01 |
| Router off for 2 h | Buffered records replayed in order | CLD-06 |
| Revoke the certificate | Red 4 Hz, no reboot loop | SEC-05 |
| 14 days of real data | Forecast within ±3 days of the actual refill date | IOT-06 |
| `cloud` tests, and `make test-all` in ChoreCore | Pass | IOT-12, CC-08 |
| `provision.py --dry-run`, then a real run | Thing, cert and policy created; device connects on the first boot | PRV-01…04 |

---

## 11. Out of Scope (v1)

Battery operation, controlling the softener, and reading data from the Culligan Accusoft board. OTA updates are planned for **v1.1**. Remote config from the ChoreCore UI (v1 uses `tools/saltmon-config.py`).

---

## 12. Open Questions

| # | Question | Default |
|---|---|---|
| — | *All questions resolved as of v0.8.* The floor-boss positions are not used: standoffs go through M3 holes drilled in the floor (MEC-05). | |

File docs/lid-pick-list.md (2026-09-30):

# SaltMon Pick List — lid panel rev 0.1

Everything for the lid panel board and its cable, for one build. Refs match `kicad/LidPanel/LidPanel.kicad_sch`;
specs come from `docs/requirements.md` §3.2, §3.3, §5.3, MEC-06 and MEC-09. The carrier and the rest of the build
are in [pick-list.md](pick-list.md). Everything is through-hole. **Have** = the part is already on hand.
DigiKey numbers were checked on 2026-09-30; stock and prices change.

## 1. Board and LEDs

| ✓ | Qty | Part | Refs | Notes |
|---|---|---|---|---|
| ☐ | 1 | Lid panel PCB, 50 × 63 mm, 2-layer, 1.6 mm | | Gerbers from `kicad/LidPanel` |
| **Have** | 1 | 5 mm flat-top LED, green | D1 FULL | |
| **Have** | 1 | 5 mm flat-top LED, yellow | D2 MID | |
| **Have** | 1 | 5 mm flat-top LED, orange | D3 LOW | |
| **Have** | 1 | 5 mm flat-top LED, red | D4 REFILL | |
| **Have** | 1 | 5 mm flat-top LED, blue | D5 DATA | |
| **Have** | 1 | 5 mm flat-top LED, purple | D6 SENS | |
| **Have** | 1 | 5 mm flat-top LED, bi-color red/green, **common cathode**, 3-lead | D7 NET | The board expects pin order R / K / G: check the part |
| **Have** | 1 | 5 mm flat-top LED, white | D8 PWR | |

## 2. LED housings (spacers)

| ✓ | Qty | Part | Refs | DigiKey | Notes |
|---|---|---|---|---|---|
| ☐ | 7 | 5 mm (T-1¾) LED spacer, nylon, **2-lead**, 10 mm long | D1–D6, D8 | [NTM-400-ND](https://www.digikey.com/en/products/result?keywords=NTM-400) (Bivar NTM-400) | 10.16 mm long, Ø5.1 mm. Fits over the leads between the board and the LED flange |
| ☐ | 1 | 5 mm LED spacer, **3-lead**, 10 mm long | D7 | [492-1104-ND](https://www.digikey.com/en/products/detail/bivar-inc/ELM-3-400/3089297) (Bivar ELM 3-400) | 10.16 mm, PVC. Cross slots plus a center hole, sold as a 3-lead 5 mm spacer: check the fit. If it doesn't fit, use a 10 mm jig while soldering: the 3 leads hold D7 steady |

**The spacer length must equal the standoff length (§4).** Together they set the gap between the board and the
lid, so each flange is pressed against the lid. Spacers are often sold in inch lengths (0.375" = 9.5 mm,
0.400" = 10.2 mm). If yours differ from 10 mm, buy standoffs of the same length. The listed 10.16 mm spacers with
10 mm standoffs give 0.16 mm of preload on each flange, which is fine.

## 3. Connector, switch and button

| ✓ | Qty | Part | Refs | DigiKey | Notes |
|---|---|---|---|---|---|
| ☐ | 1 | 2×8 shrouded (keyed) box header, 2.54 mm, **right-angle** | J1 (J_LID) | [732-2099-ND](https://www.digikey.com/en/products/detail/würth-elektronik/61201621721/2060595) (Würth 61201621721) | Fitted on the back of the board |
| **Have** | 1 | SPDT mini slide switch, panel mount, 2 A / 125 V AC | SW1 (pads J2) | | Uses the common pin and one throw |
| ☐ | 1 | Momentary push-button, normally open, panel mount, M7 bushing | SW2 (pads J3) | [EG2011-ND](https://www.digikey.com/en/products/detail/e-switch/PS1024ABLK/44576) (E-Switch PS1024ABLK) | Ø7.2 mm hole, about 15 mm behind the lid, solder lugs. Red cap: PS1024ARED |

## 4. Mounting (MEC-09)

| ✓ | Qty | Part | Refs | DigiKey | Notes |
|---|---|---|---|---|---|
| ☐ | 4 | M3 × 10 mm nylon standoffs, female–female | H1–H4 | [36-25510-ND](https://www.digikey.com/en/products/detail/keystone-electronics/25510/1532188) (Keystone 25510) | Same length as the LED spacers |
| ☐ | 4 | M3 × 6 mm screws, nylon | H1–H4 | [732-13704-ND](https://www.digikey.com/en/products/detail/würth-elektronik/97790603111/10056387) (Würth 97790603111) | Board side |
| ☐ | 4 | M3 × 8 mm self-sealing screws, stainless | | [335-1149-ND](https://www.digikey.com/en/products/detail/apm-hexseal/RM3X8MM-2701/3712297) (APM Hexseal RM3X8MM 2701) | Lid side, through the template's Ø3.2 holes. An O-ring under the head seals the hole, so no washer is needed. Check the lid thickness: 8 mm suits a lid up to about 3 mm thick |
| ☐ | — | Or: epoxy / cyanoacrylate | | | Bond the standoffs to the lid instead, so there are no screw holes |

## 5. Lid cable

| ✓ | Qty | Part | DigiKey | Notes |
|---|---|---|---|---|
| ☐ | 1 ft | 16-way 0.05" (1.27 mm) flat ribbon, 28 AWG | [3M 3365/16, per foot](https://www.digikey.com/en/products/detail/3m/3365-16/22532519) | About 20 cm plus trim |
| ☐ | 2 | 2×8 IDC ribbon socket, 2.54 mm | [609-1740-ND](https://www.digikey.com/en/products/detail/amphenol-icc-fci/71600-016LF/1002055) (Amphenol 71600-016LF) | One at each end, crimped 1:1 with the pin-1 stripe at pin 1 of both sockets. Or 3M 89116-0101 |
| ☐ | — | Or: a ready-made 2×8 IDC cable, 12" (305 mm) | [1528-2944-ND](https://www.digikey.com/en/products/result?keywords=1528-2944-ND) (Adafruit 4170) | Replaces the two rows above. Longer than needed; check stock (it had a lead time) |

## 6. Consumables

| ✓ | Part | Use |
|---|---|---|
| ☐ | Hookup wire (24–26 AWG), ~20 cm, + small heat-shrink | SW1 → J2, SW2 → J3 |
| ☐ | Neutral-cure silicone | A bead around each LED flange inside the lid (MEC-06) |
| ☐ | Glue or ribbon clamp | Cable strain relief at the lid |

## Tools

- 5 mm drill (LED holes), 3.2 mm drill (standoff screws), a 7.2 mm or 9/32" drill (PS1024 push-button; a step drill for others) and a file (switch slot).
- IDC ribbon crimp tool or a small vise.
- The printed drilling template: `kicad-cli pcb export pdf --mode-single -l User.Drawings --scale 1 -o lid-template.pdf kicad/LidPanel/LidPanel.kicad_pcb`.
  Print at 100 % and check the 50 mm bar.

## Assembly Order

1. Drill the lid from the template. Mount SW1 and SW2 in the lid.
2. Fit J1 and solder it. Put a spacer over the leads of each LED, then set the LEDs in the board, but don't solder them yet.
3. Screw the board to the standoffs, and the standoffs to the lid. Each LED passes through its hole, and the spacer
   pushes its flange against the lid. Solder and trim the LED leads from the back.
4. Wire SW1 to J2 and SW2 to J3. Seal the LED flanges with silicone. Plug in the ribbon.

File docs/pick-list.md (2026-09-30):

# SaltMon Pick List — carrier rev 0.2

One build. Refs match `kicad/DepthSensor/DepthSensor.kicad_sch`; the lid panel has its own list, [lid-pick-list.md](lid-pick-list.md); specs come from `docs/requirements.md` §3, §4 and §9.
Everything is through-hole. **Have** = the part is already on hand.

## 1. Carrier PCB — ICs, modules, sockets

| ✓ | Qty | Part | Refs | Notes |
|---|---|---|---|---|
| ☐ | 1 | ESP32-C6-DevKitM-1 (4 MB) | U1 | Espressif dev kit |
| ☐ | 2 | 1×15 female header, 2.54 mm, 8.5 mm tall | U1 socket | Rows are 22.86 mm apart; the height sets the USB-C position (MEC-04) |
| ☐ | 1 | TBD62783APG | U2 | Toshiba 8-channel source driver, DIP-18 |
| ☐ | 1 | DIP-18 socket, 7.62 mm | U2 socket | |
| ☐ | 1 | 8 × 100 kΩ bussed resistor network, SIP-9 | RN1 | Pin 1 is the common pin (e.g. Bourns 4609X-101-104LF) |

## 2. Carrier PCB — power

| ✓ | Qty | Part | Refs | Notes |
|---|---|---|---|---|
| ☐ | 1 | CUI PJ-102AH DC jack, 5.5 × 2.1 mm | J1 | |
| ☐ | 1 | PTC fuse, 0.75 A hold / 1.5 A trip, 5.1 mm lead pitch | F1 | Littelfuse RXEF075 or Bourns MF-R075 |
| ☐ | 1 | 1N5822 Schottky, DO-201AD | D1 | |
| ☐ | 1 | P6KE6.8A TVS, DO-15 | D2 | Optional |
| ☐ | 1 | 220 µF 16 V electrolytic, Ø8 mm, 3.5 mm pitch, ≤ 11.5 mm tall | C1 | The height matters (MEC-04) |

## 3. Carrier PCB — resistors (¼ W metal film, 10.16 mm pitch)

| ✓ | Qty | Value | Refs |
|---|---|---|---|
| ☐ | 2 | 100 Ω | R11, R12 |
| ☐ | 2 | 180 Ω | R1, R7 |
| ☐ | 4 | 300 Ω | R2, R3, R4, R8 |
| ☐ | 2 | 470 Ω | R5, R6 |
| ☐ | 1 | 1.5 kΩ | R9 |
| ☐ | 1 | 10 kΩ | R10 |

## 4. Carrier PCB — capacitors

| ✓ | Qty | Value | Refs | Package |
|---|---|---|---|---|
| ☐ | 4 | 100 nF ceramic | C2, C3, C4, C5 | Disc/MLCC, 5 mm pitch |
| ☐ | 2 | 1 nF ceramic | C7, C8 | Disc/MLCC, 5 mm pitch |
| ☐ | 1 | 10 µF 16 V electrolytic | C6 | Ø5 mm, 2 mm pitch |

## 5. Carrier PCB — connectors

| ✓ | Qty | Part | Refs | Notes |
|---|---|---|---|---|
| ☐ | 1 | 2×8 shrouded (keyed) box header, 2.54 mm, vertical | J3 (J_PANEL) | |
| ☐ | 1 | 2×3 shrouded (keyed) box header, 2.54 mm, vertical | J2 (J_SNS) | |
| ☐ | 1 | 1×4 male pin header, 2.54 mm | J4 (J_SPARE) | Optional |

TP1–TP6 are bare pads, and H1–H4 are holes, so there's nothing to buy for them.

## 6. Lid panel PCB

See [lid-pick-list.md](lid-pick-list.md): the board, LEDs, LED spacers, header, switch and button, mounting
hardware and the lid cable.

## 7. Sensor and cables

| ✓ | Qty | Part | Notes |
|---|---|---|---|
| ☐ | 1 (+1 spare) | US-100 ultrasonic module | Fit the UART-mode jumper |
| ☐ | ~1.3 m | 6-way 0.05" (1.27 mm) flat ribbon, 28 AWG | Sensor cable, about 1.2 m plus trim |
| ☐ | 1 | 2×3 IDC ribbon socket, 2.54 mm | Carrier end of the sensor cable |
| ☐ | 1 | 1×5 Dupont female housing + 5 crimp pins | Sensor end |
| ☐ | 1 | 2×8 IDC ribbon socket, 2.54 mm | Bench jumper plug (below). The lid cable is in the lid pick list |

**Bench jumper plug:** a spare 2×8 IDC socket with pins 11–14 shorted, so the board powers up without the lid attached (PWR-05).

## 8. Power supply

| ✓ | Qty | Part | Notes |
|---|---|---|---|
| ☐ | 1 | 5 V DC adapter, ≥ 1 A, 5.5 × 2.1 mm plug, center positive | Peak draw is about 480 mA |

## 9. Enclosure and hardware

| ✓ | Qty | Part | Notes |
|---|---|---|---|
| **Have** | 1 | Gasketed ABS junction box, about 115 × 90 × 55 mm | Mounted to the wall through its 4 corner holes (MEC-07) |
| ☐ | 4 | Wall screws + anchors for the box corners | Sized to the box's corner holes |
| ☐ | 4 | M3 × 6 mm nylon standoffs | Carrier to floor (MEC-05) |
| ☐ | 4 | M3 × 6 mm screws, nylon or stainless | Carrier to standoffs |
| ☐ | 4 | M3 screws + sealing washers | Standoffs through holes drilled in the floor |
| ☐ | 1 | Cable grommet or gland | Sensor ribbon exit in the side wall |
| ☐ | several | Small cable ties | One through the carrier's tie holes; more for strain relief |
| ☐ | 2 | Nylon M2 screws, nuts and spacers | US-100 mounted under the tank lid (SNS-04) |

## 10. Consumables

| ✓ | Part | Use |
|---|---|---|
| ☐ | Conformal coating | Back of the US-100 PCB only, not the transducers (SNS-05) |
| ☐ | Dielectric grease | Dupont contacts at the sensor |
| ☐ | Label | BLE proof-of-possession code, inside the box (SEC-01) |

## Tools you might not already have

- IDC ribbon crimp tool or a small vise, for the IDC sockets.
- Dupont crimper, for the sensor-end housing.
- A file for the USB-C cut-out (13 × 8 mm) and an 8 mm drill for the DC jack. Lid tools are in the lid pick list.

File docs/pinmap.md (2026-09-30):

# Pin Map — ESP32-C6-DevKitM-1 on the SaltMon Carrier

Source of truth for firmware (`firmware/main/board.h`) and the carrier schematic. Header pinout from
`esp32-c6-devkitm-1-schematics.pdf`. Symbol/footprint: `kicad/lib/SaltMon` (`ESP32-C6-DevKitM-1`,
pads 1–15 = J1-1…15, 16–30 = J3-1…15).

Carrier reference designators (schematic `kicad/DepthSensor/DepthSensor.kicad_sch`, generated by
`gen_schematic.py`): **J1** DC jack, **J2** J_SNS, **J3** J_PANEL, **J4** J_SPARE, **U1** kit, **U2** TBD62783APG,
**RN1** 8× 100 kΩ bussed pull-down network, R1–R8 LED, R9 power LED, R10 button pull-up, R11/R12 sensor series.
"Kit pin J1-n / J3-n" below means the kit's own headers, not the carrier's J1/J3.

## Kit Headers

| Pad | Kit pin | Kit signal | Carrier net | Use |
|---|---|---|---|---|
| 1 | J1-1 | 3V3 (LDO out) | `+3V3` | US-100 VCC via J_SNS; pull-ups |
| 2 | J1-2 | CHIP_PU (RST) | — | NC |
| 3 | J1-3 | GPIO2 | `LED_CH1` | Green, level FULL — LEDC0 |
| 4 | J1-4 | GPIO3 | `LED_CH2` | Yellow, level MID — LEDC1 |
| 5 | J1-5 | GPIO4 (strap MTMS) | — | **NC** |
| 6 | J1-6 | GPIO5 (strap MTDI) | — | **NC** |
| 7 | J1-7 | GPIO0 | `LED_CH3` | Orange, level LOW — LEDC2 |
| 8 | J1-8 | GPIO1 | `LED_CH4` | Red, REFILL — LEDC3 |
| 9 | J1-9 | GPIO8 (strap, on-board RGB LED) | — | **NC** (kit RGB LED usable by firmware) |
| 10 | J1-10 | GPIO6 | `LED_CH5` | Blue, network activity — GPIO |
| 11 | J1-11 | GPIO7 | `LED_CH6` | Purple, sensor activity — GPIO |
| 12 | J1-12 | GPIO14 | `LED_CH7` | Bi-color green, net status — LEDC4 |
| 13 | J1-13 | GND | `GND` | |
| 14 | J1-14 | 5V | `V_SYS` | Power in from D1 (≈ 4.6 V) |
| 15 | J1-15 | GND | `GND` | |
| 16 | J3-1 | GND | `GND` | |
| 17 | J3-2 | GPIO16 / U0TXD | — | **NC** (console via CP2102N) |
| 18 | J3-3 | GPIO17 / U0RXD | — | **NC** |
| 19 | J3-4 | GPIO23 | `SNS_RX` | UART1 RX ← US-100 Trig/TX (100 Ω series) |
| 20 | J3-5 | GPIO22 | `SNS_TX` | UART1 TX → US-100 Echo/RX (100 Ω series) |
| 21 | J3-6 | GPIO21 | `SPARE_B` | J_SPARE-4 |
| 22 | J3-7 | GPIO20 | `SPARE_A` | J_SPARE-3 |
| 23 | J3-8 | GPIO19 | `BTN_N` | Lid push-button to GND, 10 kΩ pull-up + 100 nF, active low |
| 24 | J3-9 | GPIO18 | `LED_CH8` | Bi-color red, net status — LEDC5 |
| 25 | J3-10 | GPIO15 (strap) | — | **NC** |
| 26 | J3-11 | GPIO9 (strap, BOOT button) | — | **NC** |
| 27 | J3-12 | GND | `GND` | |
| 28 | J3-13 | GPIO13 / USB D+ | — | **NC** |
| 29 | J3-14 | GPIO12 / USB D− | — | **NC** |
| 30 | J3-15 | GND | `GND` | |

## Carrier Connectors

### J_SNS — 2×3 shrouded, to US-100 (ribbon ~1.2 m)

| Pin | Net | US-100 pin (Dupont 1×5) |
|---|---|---|
| 1 | `+3V3` | VCC |
| 2 | `SNS_TX_C` (from GPIO22 via 100 Ω) | Echo/RX |
| 3 | `SNS_RX_C` (to GPIO23 via 100 Ω) | Trig/TX |
| 4 | `GND` | GND |
| 5 | `GND` | GND |
| 6 | — | not connected |

The US-100 UART-mode jumper must be installed.

### J_PANEL — 2×8 shrouded, to the lid panel's J_LID (1:1 ribbon, ~20 cm)

| Pin | Net | Lid part | | Pin | Net | Lid part |
|---|---|---|---|---|---|---|
| 1 | `LED_A1` | Green anode | | 2 | `LED_A2` | Yellow anode |
| 3 | `LED_A3` | Orange anode | | 4 | `LED_A4` | Red anode |
| 5 | `LED_A5` | Blue anode | | 6 | `LED_A6` | Purple anode |
| 7 | `LED_A7` | Bi-color green anode | | 8 | `LED_A8` | Bi-color red anode |
| 9 | `LED_PWR` | White anode | | 10 | `BTN_N` | Push-button |
| 11 | `SW_A` | Switch common | | 12 | `SW_A` | Switch common |
| 13 | `SW_B` | Switch throw | | 14 | `SW_B` | Switch throw |
| 15 | `GND` | LED cathodes, button | | 16 | `GND` | LED cathodes, button |

`LED_An` = U2 OUTn → current resistor on the carrier (values in requirements §5.1). J_LID on the lid panel
(`kicad/LidPanel`) has the same pin numbers and nets. On the lid board, D7 pin 1 = red (`LED_A8`), pin 2 = K, pin 3 = green (`LED_A7`).

### J_SPARE — 1×4

| Pin | Net |
|---|---|
| 1 | `+3V3` |
| 2 | `GND` |
| 3 | `SPARE_A` (GPIO20) |
| 4 | `SPARE_B` (GPIO21) |

## U2 TBD62783APG (DIP-18)

| U2 pin | Signal | U2 pin | Signal |
|---|---|---|---|
| 1 IN1 | `LED_CH1` | 18 OUT1 | → R1 → `LED_A1` |
| 2 IN2 | `LED_CH2` | 17 OUT2 | → R2 → `LED_A2` |
| 3 IN3 | `LED_CH3` | 16 OUT3 | → R3 → `LED_A3` |
| 4 IN4 | `LED_CH4` | 15 OUT4 | → R4 → `LED_A4` |
| 5 IN5 | `LED_CH5` | 14 OUT5 | → R5 → `LED_A5` |
| 6 IN6 | `LED_CH6` | 13 OUT6 | → R6 → `LED_A6` |
| 7 IN7 | `LED_CH7` | 12 OUT7 | → R7 → `LED_A7` |
| 8 IN8 | `LED_CH8` | 11 OUT8 | → R8 → `LED_A8` |
| 9 VCC | `V_SYS` | 10 GND | `GND` |

Each IN has a 100 kΩ pull-down to GND.

Pin assignment checked against the KiCad `Transistor_Array:TBD62783A` symbol (pin 9 VCC, pin 10 GND).

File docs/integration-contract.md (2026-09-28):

# SaltMon Integration Contract — v1

The only interface between the `SaltMon-<env>` stack (this repo) and its consumers (ChoreCore's `softener`
feature). Normative source: `docs/requirements.md` §8.1 and §8.3. If the two differ, this document wins for
consumers, and the requirements must be corrected.

## 1. Discovery

| SSM parameter (us-east-1, account 345482189436) | Value |
|---|---|
| `/saltmon/<env>/readings-topic-arn` | ARN of SNS topic `SaltMon-<env>-readings` |
| `/saltmon/<env>/contract-version` | `1` |

Consumers resolve the ARN at synth or deploy time (`ssm.StringParameter.valueForStringParameter`). There are no
CloudFormation exports, so either stack can be redeployed independently. SaltMon must be deployed first.

## 2. Subscribing

- Standard SNS topic, SSE with a SaltMon customer-managed KMS key.
- Subscribe an **SQS queue** (with DLQ) in the same account, with **raw message delivery enabled**. The key policy
  already lets SNS encrypt into subscriber queues in this account. The consumer queue must use its own KMS key or
  SQS-managed SSE.
- Only principals in account `345482189436` may subscribe.
- Filter with message attributes if desired, e.g. `{"kind": ["forecast", "status", "event"]}`.

| Message attribute | Type | Values |
|---|---|---|
| `kind` | String | `telemetry`, `event`, `forecast`, `status` |
| `thing` | String | `saltmon-<6 hex>` |

## 3. Envelope

```json
{
  "contract": 1,
  "kind": "forecast",
  "thing": "saltmon-a1b2c3",
  "ts": 1790000000000,
  "received_at": 1790000000321,
  "data": { }
}
```

| Field | Type | Meaning |
|---|---|---|
| `contract` | int | Contract major version. Ignore messages with an unknown value. |
| `kind` | string | Selects the shape of `data`. |
| `thing` | string | IoT thing name. The consumer maps it to a family in its own config. |
| `ts` | int, epoch ms | Device time for `telemetry`/`event`, and compute time for `forecast`/`status`. |
| `received_at` | int, epoch ms | When SaltMon stored or produced the record. |
| `data` | object | Kind-specific, below. |

## 4. `data` by kind

### `telemetry` (every ~10 min)

| Field | Type | Notes |
|---|---|---|
| `schema` | int | Device schema, `1` |
| `seq` | int | Device sequence counter, resets on reboot |
| `distance_mm` | int \| null | Median of the valid samples; null if none |
| `distance_min_mm`, `distance_max_mm` | int \| null | |
| `valid`, `samples` | int | Valid and total sample count in the burst |
| `level_pct` | number \| null | 0–100, from `d_full_mm`/`d_low_mm` |
| `state` | string | `OK`, `REFILL`, `FAULT`, `OBSTRUCTED`, `UNCALIBRATED` |
| `bridge_suspected` | bool | Salt bridge hint |
| `temp_c` | number | US-100 temperature |
| `rssi_dbm` | int | |
| `uptime_s` | int | |
| `fw` | string | Semver |

### `event`

| Field | Type | Notes |
|---|---|---|
| `schema`, `seq` | int | |
| `type` | string | `boot`, `state_change`, `refill_detected`, `bridge_suspected`, `sensor_fault` |
| `from`, `to` | string \| null | States, for `state_change` |
| `detail` | string \| null | Free text |
| `reset_reason`, `fw` | string | `boot` only |

### `forecast` (hourly)

| Field | Type | Notes |
|---|---|---|
| `level_pct` | number | Latest hourly median |
| `rate_in_per_day` | number \| null | Salt height consumed per day |
| `rate_lb_per_day` | number \| null | At 10.3 lb/in |
| `refill_eta` | int \| null | Epoch ms when the level reaches `refill_pct` |
| `days_to_refill` | number \| null | 0 if already at or below `refill_pct` |
| `confidence` | string | `high`, `low`, `insufficient` (then ETA and rates are null) |
| `r2` | number \| null | |
| `points` | int | Hourly points used |

### `status` (transitions only)

| Field | Type | Notes |
|---|---|---|
| `online` | bool | false after > 1 h without telemetry |
| `last_seen` | int | Epoch ms of the last telemetry |

## 5. Delivery Semantics

- **At least once, unordered.** De-duplicate on (`thing`, `kind`, `ts`).
- Use `ts` to discard stale records (e.g. a late `forecast` older than the one stored).
- SaltMon publishes only records it stored for the first time, so duplicates come only from SNS/SQS retries.

## 6. Evolution

- Within `contract: 1`, fields are only **added**. Consumers must ignore unknown fields and unknown `kind`s.
- A breaking change bumps `contract`, is published side by side on a new topic, and gets a new SSM parameter.
  The v1 topic keeps running until every consumer has moved.

## 7. Consumer Obligations (ChoreCore)

- Read-only toward the device and SaltMon. No calls back into SaltMon in v1.
- The sensor never completes a chore (ChoreCore INV-01).
- Failed messages go to the DLQ; the consumer alarms on DLQ depth > 0.

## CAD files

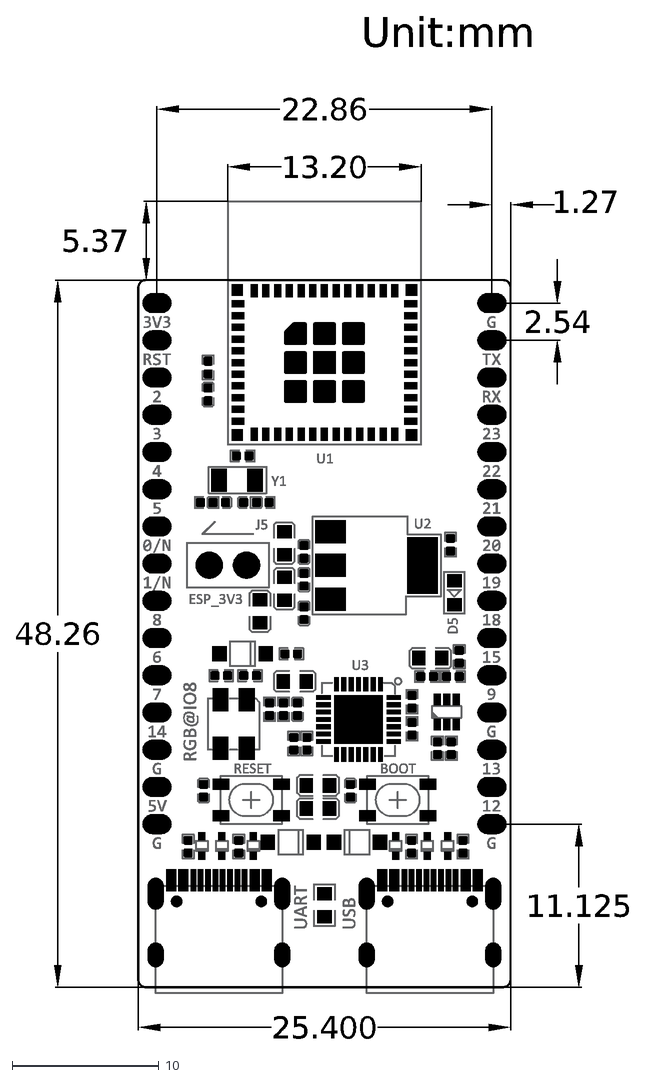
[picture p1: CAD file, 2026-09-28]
docs/esp32-c6-devkitm-1-dimensions.dxf
48.26
2.54
11.125
1.27
Unit:mm
25.400
13.20
5.37
22.86

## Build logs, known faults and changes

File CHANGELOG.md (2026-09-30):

# Changelog

All notable changes to this project are documented here. The format follows
[Keep a Changelog](https://keepachangelog.com/en/1.1.0/). Hardware revisions are named after the carrier PCB
revision.

## [Unreleased]

### Added
- README and CHANGELOG.
- **Lid panel PCB rev 0.1** (`kicad/LidPanel`), replacing the hand-wired lid (requirements v0.8: D-10, §3.2, §5.3,
  MEC-06, MEC-09). It is 50 × 63 mm and passive: 8 flat-top 5 mm LEDs, J2/J3 pads for the panel switch and button,
  and a right-angle 2×8 header J_LID wired 1:1 to J_PANEL. ERC and DRC clean, schematic parity clean.
  - The 1:1 lid drilling template is on the board's User.Drawings layer.
  - The lid ribbon now has an IDC socket at both ends. Bezels, the GND bus wire and most heat-shrink are gone.
  - `docs/lid-pick-list.md`: the lid board's own pick list, with 10 mm nylon LED spacers as the LED housings, and an
    assembly order.
- `kicad/lib/schgen.py` and `kicad/lib/pcbgen.py`: generator helpers shared by both boards. The carrier's
  generators now use them, with unchanged output.

### Changed
- **Carrier rev 0.2:** removed the top tab, which held no parts. The board is now 80.5 × 92 mm, with only the
  bottom tab (the kit's USB end and J1 must reach the bottom wall, MEC-03). The silkscreen reads v0.2.
  - Rerouted. C4 and J4 moved 0.5 mm down, and a fixed +3V3 stub leads U1 pad 1 out from under the antenna slot
    (`PREROUTE` in `gen_pcb.py`).
  - DRC: 0 errors, 0 unconnected items, schematic parity clean.
  - The Gerbers in `depth_gerber/` are still rev 0.1 and must be re-exported.

## [carrier-0.1] — 2026-09-28

First complete carrier design, ready for fabrication.

### Added
- **Requirements** (`docs/requirements.md`, draft v0.7): a design-decisions log, components, the power path and
  budget, LED behavior, sensor and MCU I/O, firmware, the two-stack cloud design (SaltMon + ChoreCore consumer),
  enclosure mechanics, and a verification plan.
- **Pin map** (`docs/pinmap.md`): the kit header pads, J_SNS, J_PANEL, J_SPARE and the U2 pinout.
- **Integration contract** (`docs/integration-contract.md`, contract v1): SSM discovery, the SNS/SQS subscription,
  the message envelope, the payload for each kind, delivery semantics and the evolution rules.
- **Pick list** (`docs/pick-list.md`) for one complete build.
- **KiCad library** (`kicad/lib/`): an ESP32-C6-DevKitM-1 symbol and a socketed footprint with the antenna
  keep-out, generated by `gen_devkit.py`.
- **Carrier schematic**, generated by `gen_schematic.py`. ERC is clean. The UUIDs are deterministic, so
  regenerating keeps the links to the PCB.
- **Carrier PCB**, generated by `gen_pcb.py`:
  - 80.5 × 106 mm board with four notched corners, an antenna slot and cable-tie holes;
  - placement, autorouting with Freerouting 2.4.1, and a GND pour on both layers;
  - power net classes: 0.4–0.8 mm tracks.
  - DRC: 0 errors, 0 unconnected items, schematic parity clean.
- Gerbers and drill files (`kicad/DepthSensor/depth_gerber/`).

### Changed
- MEC-07: the box is mounted through its 4 corner holes. The wall-screw keep-clear zones on the carrier were
  removed.
- Test points and mounting holes are excluded from the BOM.

### Known Issues
- DRC warning: the J1 (PJ-102AH) footprint differs from the library copy, because its silkscreen is trimmed at
  the board edge. Expected.

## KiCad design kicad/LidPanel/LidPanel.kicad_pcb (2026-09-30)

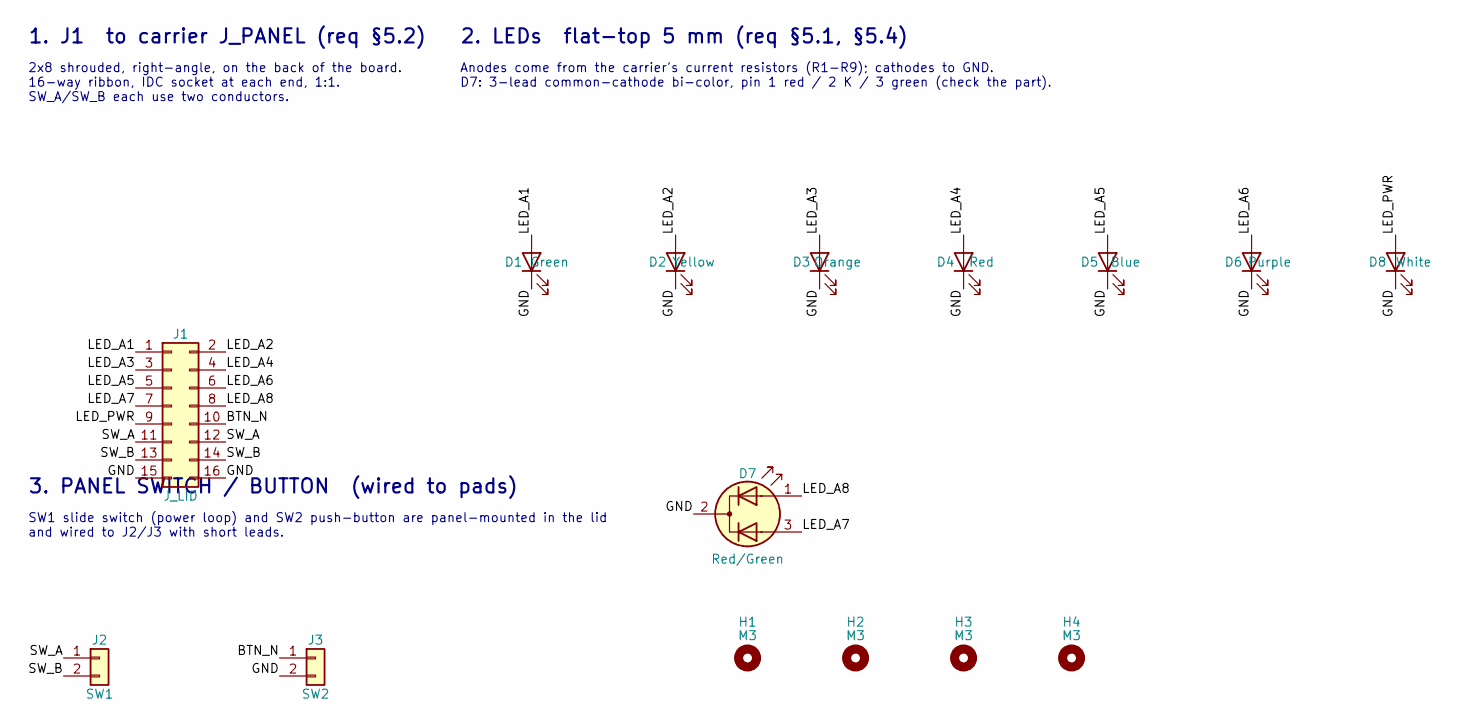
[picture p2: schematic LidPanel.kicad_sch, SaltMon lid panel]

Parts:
D1: Green; LED_D5.0mm_FlatTop
D2: Yellow; LED_D5.0mm_FlatTop
D3: Orange; LED_D5.0mm_FlatTop
D4: Red; LED_D5.0mm_FlatTop
D5: Blue; LED_D5.0mm_FlatTop
D6: Purple; LED_D5.0mm_FlatTop
D7: Red/Green; LED_D5.0mm-3
D8: White; LED_D5.0mm_FlatTop
H1, H2, H3, H4: M3; MountingHole_3.2mm_M3
J1: J_LID; IDC-Header_2x08_P2.54mm_Horizontal
J2: SW1; SolderWire-0.5sqmm_1x02_P4.6mm_D0.9mm_OD2.1mm
J3: SW2; SolderWire-0.5sqmm_1x02_P4.6mm_D0.9mm_OD2.1mm

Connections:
/BTN_N: J1.10, J3.1
/GND: D1.1 (K), D2.1 (K), D3.1 (K), D4.1 (K), D5.1 (K), D6.1 (K), D7.2 (K), D8.1 (K), J1.15, J1.16, J3.2
/LED_A1: D1.2 (A), J1.1
/LED_A2: D2.2 (A), J1.2
/LED_A3: D3.2 (A), J1.3
/LED_A4: D4.2 (A), J1.4
/LED_A5: D5.2 (A), J1.5
/LED_A6: D6.2 (A), J1.6
/LED_A7: D7.3 (A2), J1.7
/LED_A8: D7.1 (A1), J1.8
/LED_PWR: D8.2 (A), J1.9
/SW_A: J1.11, J1.12, J2.1
/SW_B: J1.13, J1.14, J2.2

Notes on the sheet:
1. J1 to carrier J_PANEL (req §5.2)
2x8 shrouded, right-angle, on the back of the board. 16-way ribbon, IDC socket at each end, 1:1. SW_A/SW_B each use two conductors.
2. LEDs flat-top 5 mm (req §5.1, §5.4)
Anodes come from the carrier's current resistors (R1-R9); cathodes to GND. D7: 3-lead common-cathode bi-color, pin 1 red / 2 K / 3 green (check the part).
3. PANEL SWITCH / BUTTON (wired to pads)
SW1 slide switch (power loop) and SW2 push-button are panel-mounted in the lid and wired to J2/J3 with short leads.

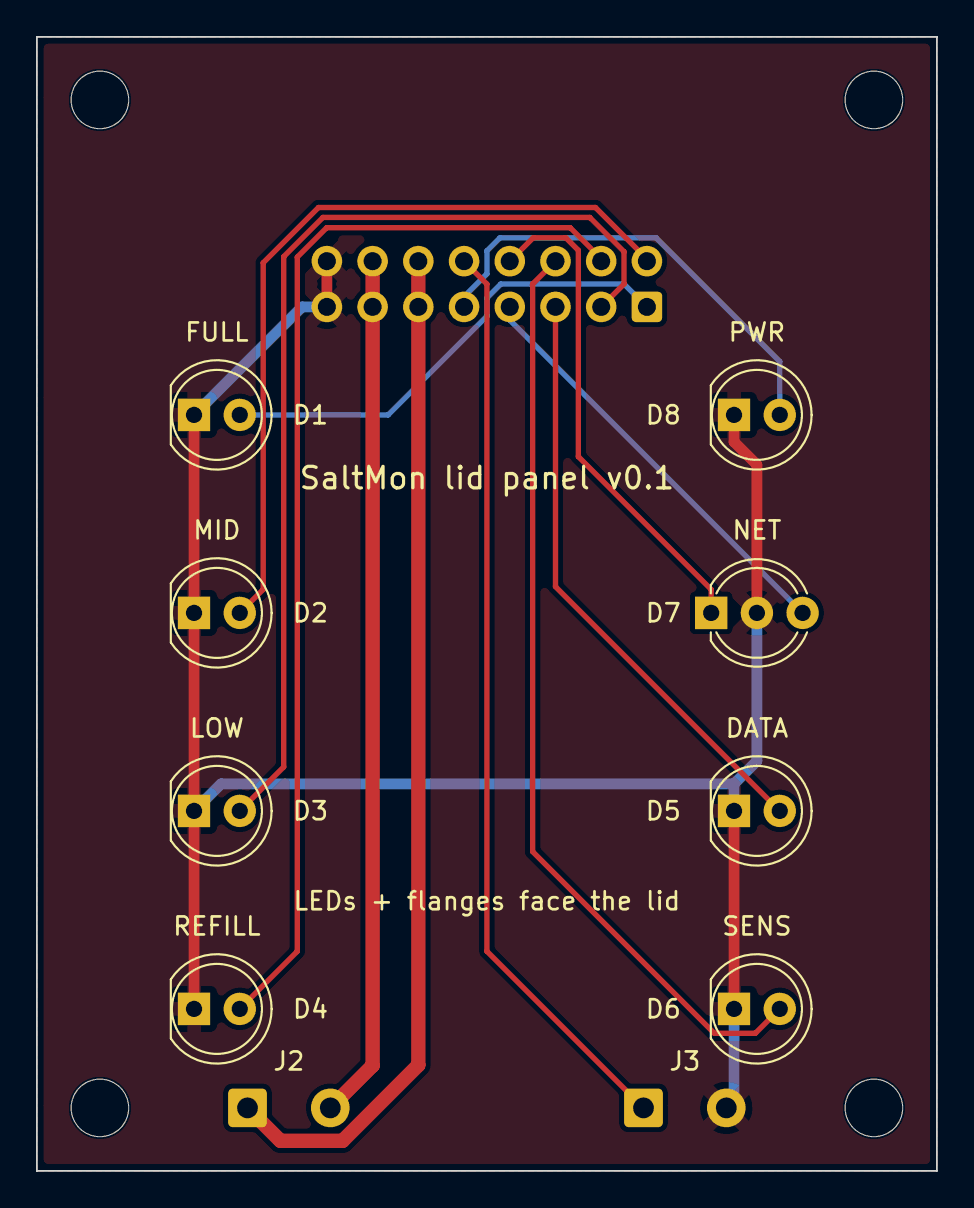
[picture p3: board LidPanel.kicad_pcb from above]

Board: 2 copper layers, 50.0 x 63.0 mm, 15 parts (1 on the bottom side), 13 nets.

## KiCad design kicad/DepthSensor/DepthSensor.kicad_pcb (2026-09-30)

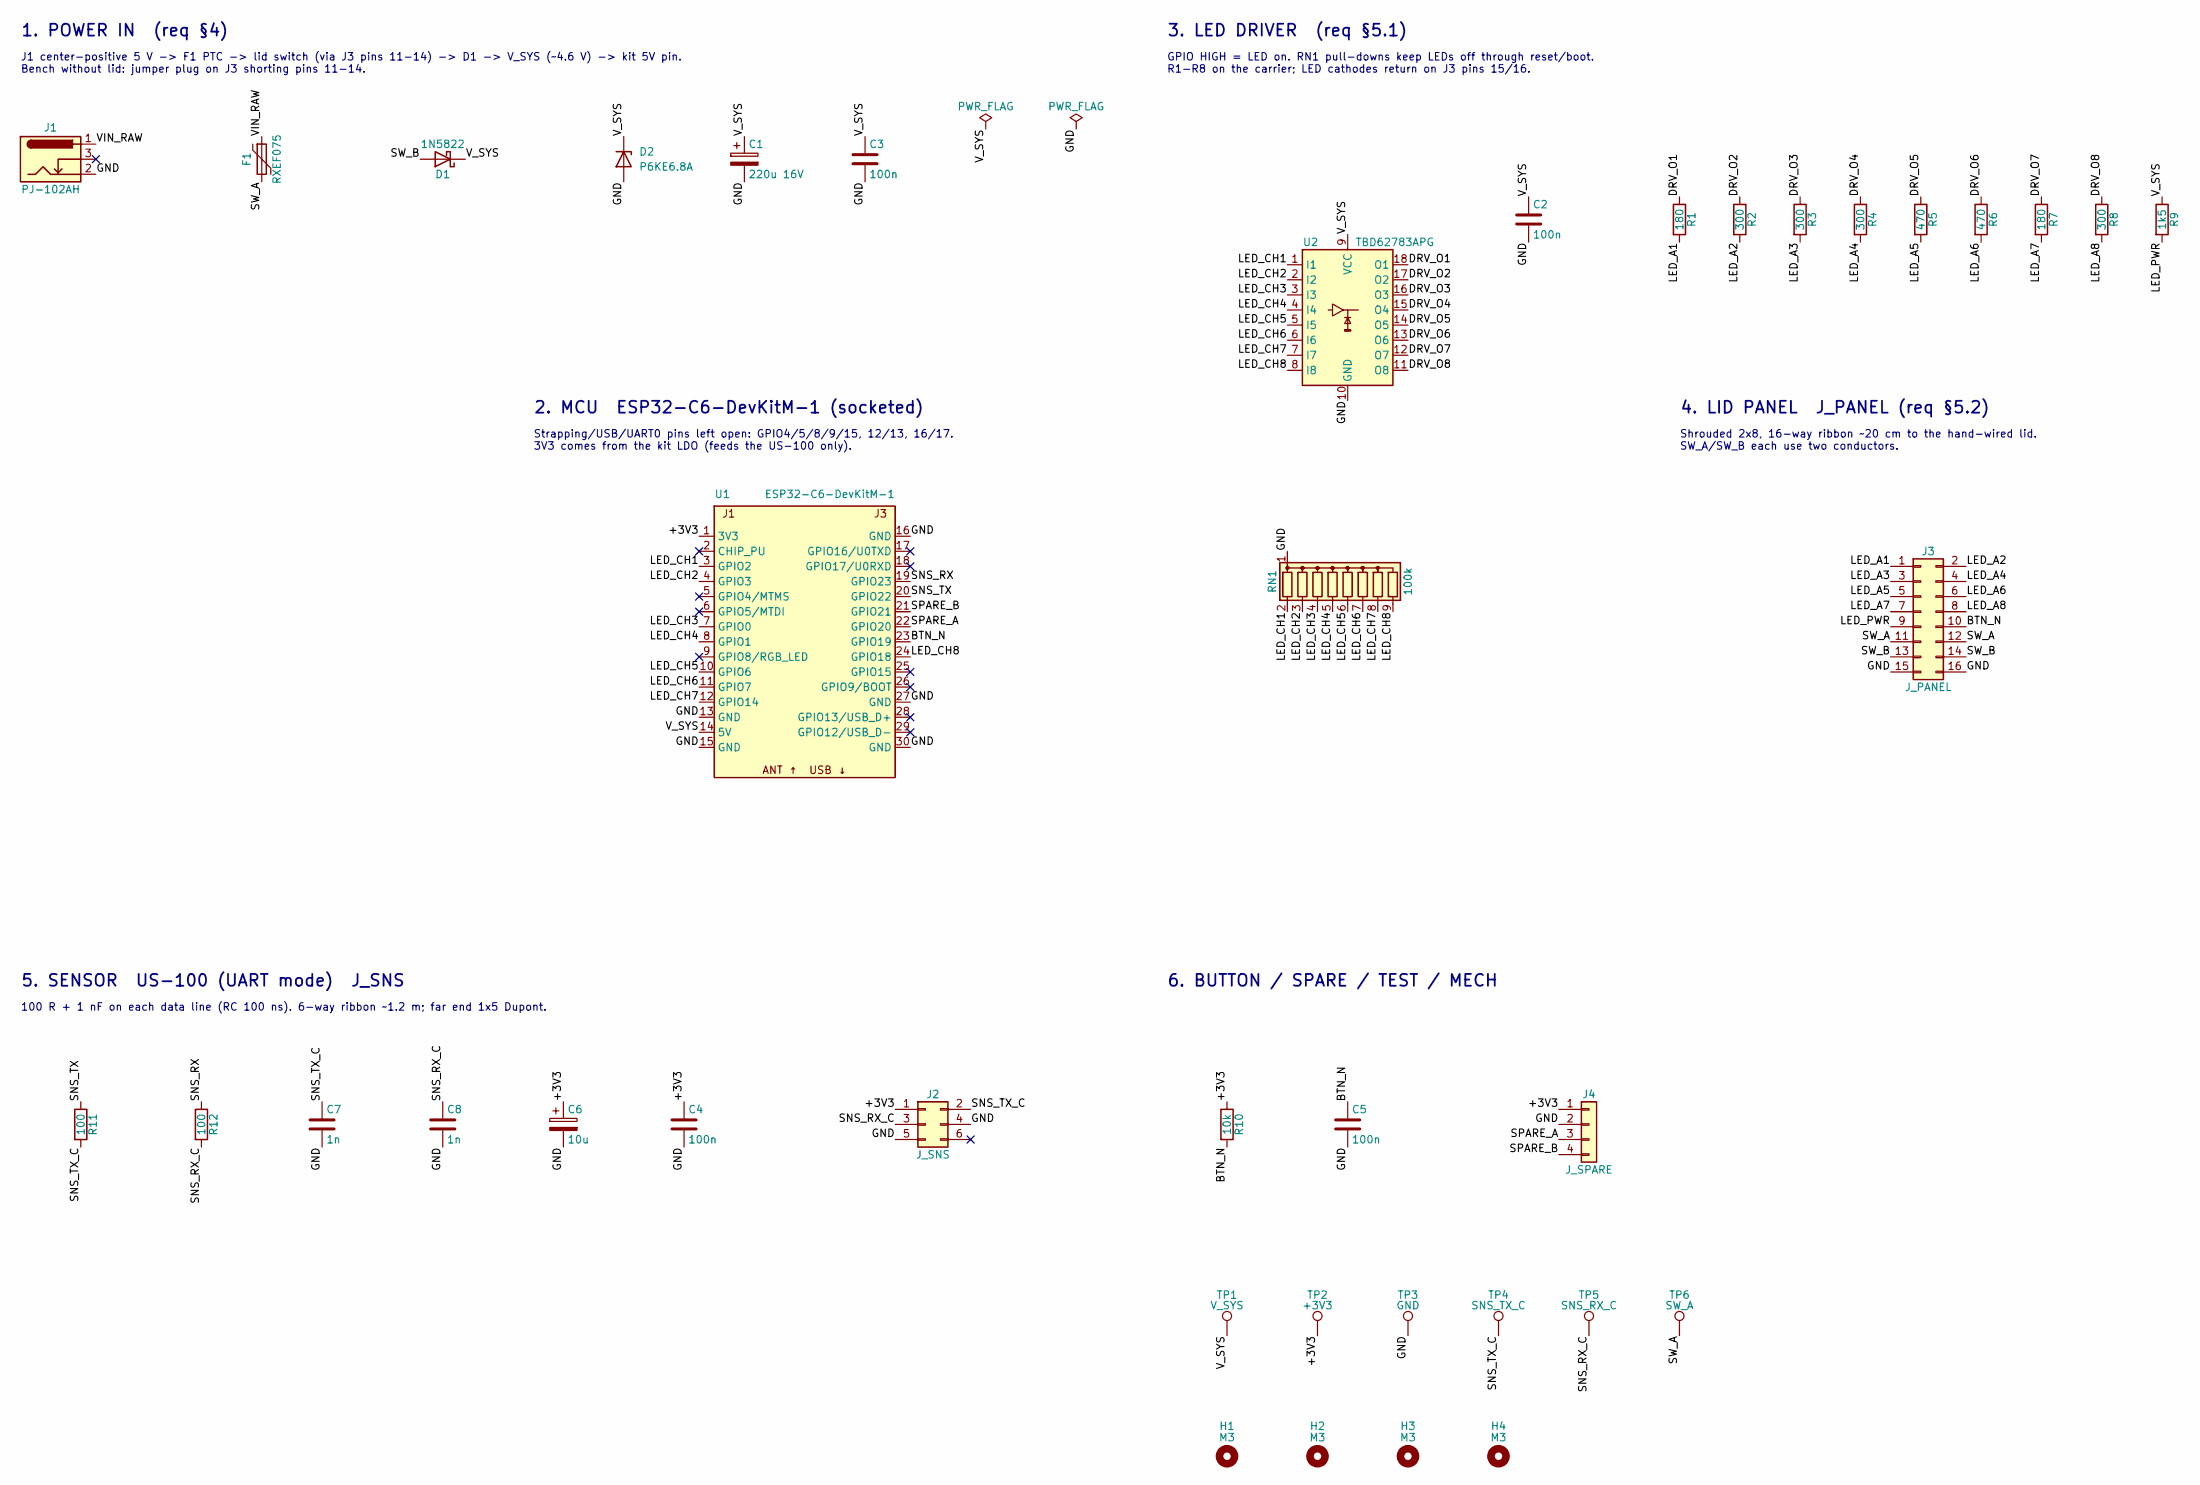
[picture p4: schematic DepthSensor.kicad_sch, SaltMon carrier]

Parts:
C1: 220u 16V; CP_Radial_D8.0mm_P3.50mm
C2, C3, C4, C5: 100n; C_Disc_D5.0mm_W2.5mm_P5.00mm
C6: 10u; CP_Radial_D5.0mm_P2.00mm
C7, C8: 1n; C_Disc_D5.0mm_W2.5mm_P5.00mm
D1: 1N5822; D_DO-201AD_P15.24mm_Horizontal
D2: P6KE6.8A; D_DO-15_P10.16mm_Horizontal
F1: RXEF075; Fuse_Bourns_MF-RHT070
H1, H2, H3, H4: M3; MountingHole_3.2mm_M3
J1: PJ-102AH; BarrelJack_CUI_PJ-102AH_Horizontal
J2: J_SNS; IDC-Header_2x03_P2.54mm_Vertical
J3: J_PANEL; IDC-Header_2x08_P2.54mm_Vertical
J4: J_SPARE; PinHeader_1x04_P2.54mm_Vertical
R1, R7: 180; R_Axial_DIN0207_L6.3mm_D2.5mm_P10.16mm_Horizontal
R2, R3, R4, R8: 300; R_Axial_DIN0207_L6.3mm_D2.5mm_P10.16mm_Horizontal
R5, R6: 470; R_Axial_DIN0207_L6.3mm_D2.5mm_P10.16mm_Horizontal
R9: 1k5; R_Axial_DIN0207_L6.3mm_D2.5mm_P10.16mm_Horizontal
R10: 10k; R_Axial_DIN0207_L6.3mm_D2.5mm_P10.16mm_Horizontal
R11, R12: 100; R_Axial_DIN0207_L6.3mm_D2.5mm_P10.16mm_Horizontal
RN1: 100k; R_Array_SIP9
TP1: V_SYS; TestPoint_THTPad_1.5x1.5mm_Drill0.7mm
TP2: +3V3; TestPoint_THTPad_1.5x1.5mm_Drill0.7mm
TP3: GND; TestPoint_THTPad_1.5x1.5mm_Drill0.7mm
TP4: SNS_TX_C; TestPoint_THTPad_1.5x1.5mm_Drill0.7mm
TP5: SNS_RX_C; TestPoint_THTPad_1.5x1.5mm_Drill0.7mm
TP6: SW_A; TestPoint_THTPad_1.5x1.5mm_Drill0.7mm
U1: ESP32-C6-DevKitM-1; ESP32-C6-DevKitM-1_Socketed
U2: TBD62783APG; DIP-18_W7.62mm_Socket

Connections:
/+3V3: C4.1, C6.1, J2.1, J4.1, R10.1, TP2.1, U1.1 (3V3)
/BTN_N: C5.1, J3.10, R10.2, U1.23 (GPIO19)
/DRV_O1: R1.1, U2.18 (O1)
/DRV_O2: R2.1, U2.17 (O2)
/DRV_O3: R3.1, U2.16 (O3)
/DRV_O4: R4.1, U2.15 (O4)
/DRV_O5: R5.1, U2.14 (O5)
/DRV_O6: R6.1, U2.13 (O6)
/DRV_O7: R7.1, U2.12 (O7)
/DRV_O8: R8.1, U2.11 (O8)
/GND: C1.2, C2.2, C3.2, C4.2, C5.2, C6.2, C7.2, C8.2, D2.2 (A), J1.2, J2.4, J2.5, J3.15, J3.16, J4.2, RN1.1 (common), TP3.1, U1.13 (GND), U1.15 (GND), U1.16 (GND), U1.27 (GND), U1.30 (GND), U2.10 (GND)
/LED_A1: J3.1, R1.2
/LED_A2: J3.2, R2.2
/LED_A3: J3.3, R3.2
/LED_A4: J3.4, R4.2
/LED_A5: J3.5, R5.2
/LED_A6: J3.6, R6.2
/LED_A7: J3.7, R7.2
/LED_A8: J3.8, R8.2
/LED_CH1: RN1.2 (R1), U1.3 (GPIO2), U2.1 (I1)
/LED_CH2: RN1.3 (R2), U1.4 (GPIO3), U2.2 (I2)
/LED_CH3: RN1.4 (R3), U1.7 (GPIO0), U2.3 (I3)
/LED_CH4: RN1.5 (R4), U1.8 (GPIO1), U2.4 (I4)
/LED_CH5: RN1.6 (R5), U1.10 (GPIO6), U2.5 (I5)
/LED_CH6: RN1.7 (R6), U1.11 (GPIO7), U2.6 (I6)
/LED_CH7: RN1.8 (R7), U1.12 (GPIO14), U2.7 (I7)
/LED_CH8: RN1.9 (R8), U1.24 (GPIO18), U2.8 (I8)
/LED_PWR: J3.9, R9.2
/SNS_RX: R12.1, U1.19 (GPIO23)
/SNS_RX_C: C8.1, J2.3, R12.2, TP5.1
/SNS_TX: R11.1, U1.20 (GPIO22)
/SNS_TX_C: C7.1, J2.2, R11.2, TP4.1
/SPARE_A: J4.3, U1.22 (GPIO20)
/SPARE_B: J4.4, U1.21 (GPIO21)
/SW_A: F1.2, J3.11, J3.12, TP6.1
/SW_B: D1.2 (A), J3.13, J3.14
/VIN_RAW: F1.1, J1.1
/V_SYS: C1.1, C2.1, C3.1, D1.1 (K), D2.1 (K), R9.1, TP1.1, U1.14 (5V), U2.9 (VCC)

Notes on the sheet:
1. POWER IN (req §4)
J1 center-positive 5 V -> F1 PTC -> lid switch (via J3 pins 11-14) -> D1 -> V_SYS (~4.6 V) -> kit 5V pin. Bench without lid: jumper plug on J3 shorting pins 11-14.
2. MCU ESP32-C6-DevKitM-1 (socketed)
Strapping/USB/UART0 pins left open: GPIO4/5/8/9/15, 12/13, 16/17. 3V3 comes from the kit LDO (feeds the US-100 only).
3. LED DRIVER (req §5.1)
GPIO HIGH = LED on. RN1 pull-downs keep LEDs off through reset/boot. R1-R8 on the carrier; LED cathodes return on J3 pins 15/16.
4. LID PANEL J_PANEL (req §5.2)
Shrouded 2x8, 16-way ribbon ~20 cm to the hand-wired lid. SW_A/SW_B each use two conductors.
5. SENSOR US-100 (UART mode) J_SNS
100 R + 1 nF on each data line (RC 100 ns). 6-way ribbon ~1.2 m; far end 1x5 Dupont.
6. BUTTON / SPARE / TEST / MECH

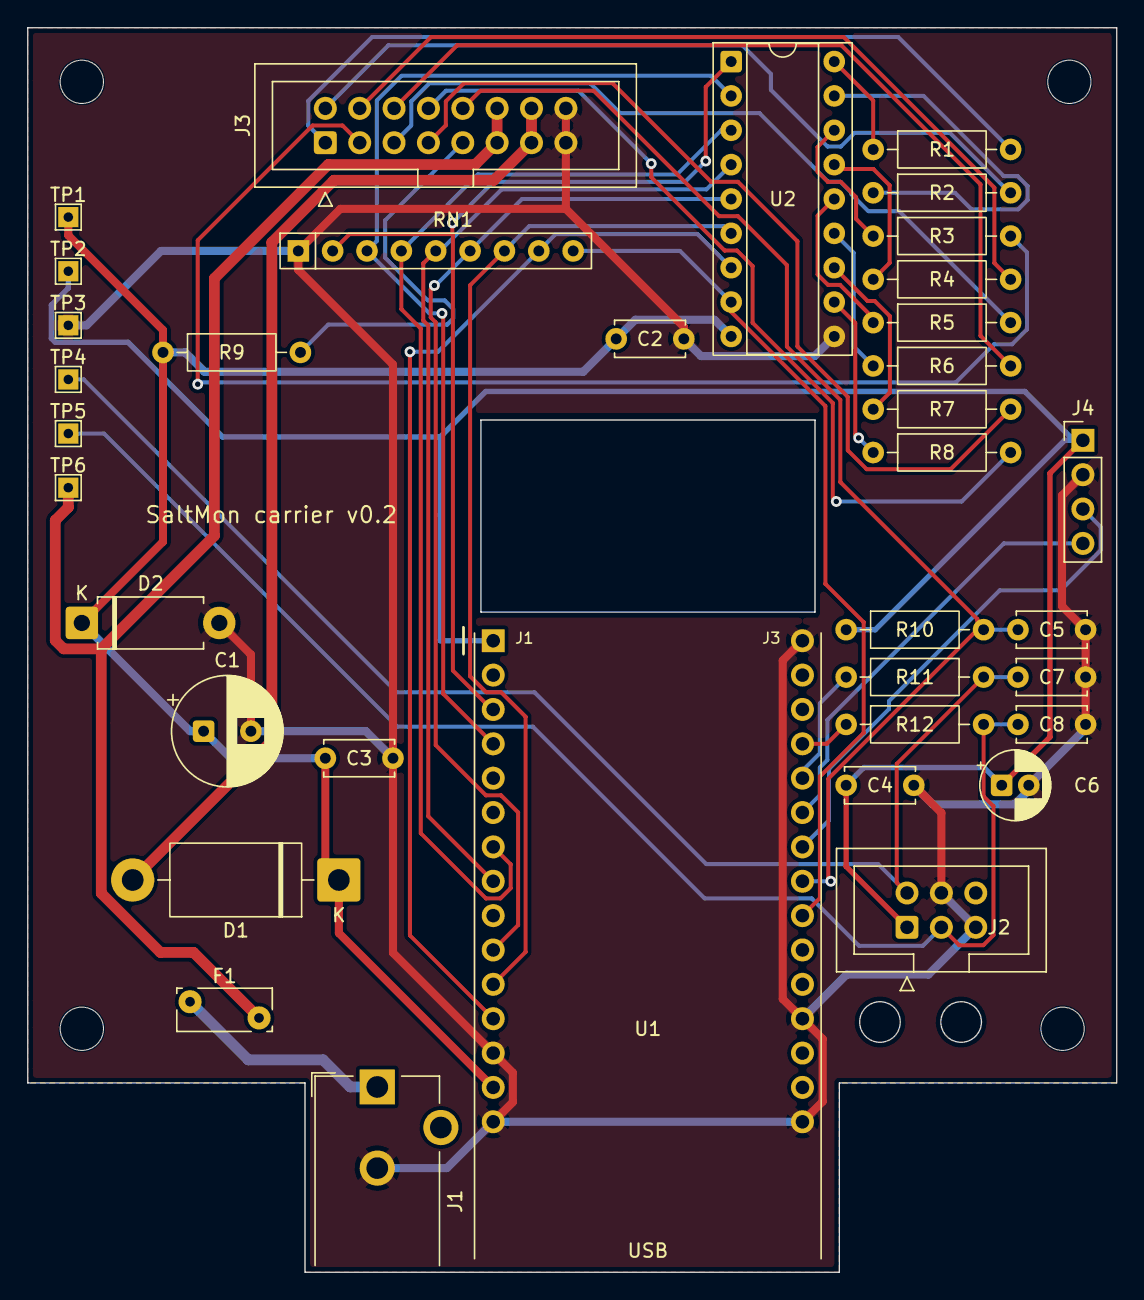
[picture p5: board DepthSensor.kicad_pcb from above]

Board: 2 copper layers, 80.5 x 92.0 mm, 40 parts (0 on the bottom side), 38 nets.

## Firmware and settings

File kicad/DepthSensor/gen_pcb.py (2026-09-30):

#!/usr/bin/env python3
"""Build the SaltMon carrier PCB: outline, placement, rules, then autoroute with Freerouting.

Must run under KiCad's bundled Python (it needs `pcbnew`):
  KPY=/Applications/KiCad/KiCad.app/Contents/Frameworks/Python.framework/Versions/Current/bin/python3
  $KPY kicad/DepthSensor/gen_pcb.py            # place + route + pour
  $KPY kicad/DepthSensor/gen_pcb.py --no-route # place only (inspect before routing)

Inputs: DepthSensor.kicad_sch (via kicad-cli netlist export), kicad/freerouting/freerouting-*.jar
(not in git: download from https://github.com/freerouting/freerouting/releases, tested with 2.4.1; needs Java 21+).
Geometry: docs/requirements.md §9 (MEC-02…MEC-08). Board coords: origin at (100, 100) = top-left of the
board bounding box, portrait, +Y down toward the bottom wall (USB-C cut-out + DC jack).
"""
import sys
from pathlib import Path

import pcbnew

HERE = Path(__file__).resolve().parent
sys.path.insert(0, str(HERE.parent / "lib"))
from pcbgen import (add_footprints, add_nets, add_tracks, edge_circle, edge_poly, gnd_pour, mm, netlist, pt,  # noqa: E402
                    route, rules, strip_board)

PCB = HERE / "DepthSensor.kicad_pcb"
SCH = HERE / "DepthSensor.kicad_sch"
BUILD = HERE / "build"

# ---------------------------------------------------------------- geometry (mm)
X0, Y0 = 100.0, 100.0
W, H = 80.5, 106.0            # MEC-02 bounding box of the old two-tab outline; the top edge is now at Y0 + NH
NW, NH = 20.5, 14.0           # corner notches (across width x along length)
SLOT = (133.5, 143.0, 158.2, 157.2)       # antenna slot under the kit overhang (x0, y0, x1, y1)
TIE_HOLES = [(163.0, 187.5), (169.0, 187.5)]  # sensor-ribbon cable tie, Ø3
HOLES = {"H1": (104.0, 118.0), "H2": (177.0, 118.0), "H3": (104.0, 188.0), "H4": (176.5, 188.0)}

# ---------------------------------------------------------------- placement: ref -> (x, y, rotation°)
PLACE = {
    # bottom tab: DC jack (front flush with bottom edge) + kit (USB end flush, antenna up)
    "J1": (125.84, 192.3, 0),
    "U1": (134.41, 159.315, 0),
    # top: lid-panel header, LED driver, pull-downs, LED resistors
    "J3": (122.0, 122.5, 90),
    "U2": (152.0, 116.5, 0),
    "C2": (143.5, 137.0, 0),
    "RN1": (120.0, 130.5, 0),
    **{f"R{i + 1}": (162.5, 123.0 + 3.2 * i, 0) for i in range(8)},
    "R9": (110.0, 138.0, 0),
    # left: power path
    "F1": (112.0, 186.0, 0),
    "D1": (123.0, 177.0, 180),
    "C1": (113.0, 166.0, 0),
    "D2": (104.0, 158.0, 0),
    "C3": (122.0, 168.0, 0),
    # right: sensor interface, button, spare
    "R10": (160.5, 158.5, 0), "C5": (173.2, 158.5, 0),
    "R11": (160.5, 162.0, 0), "C7": (173.2, 162.0, 0),
    "R12": (160.5, 165.5, 0), "C8": (173.2, 165.5, 0),
    "C4": (160.5, 170.0, 0), "C6": (172.0, 170.0, 0),
    "J2": (165.0, 180.5, 90),
    "J4": (178.0, 144.5, 0),
    # test pads down the left edge
    **{f"TP{i + 1}": (103.0, 128.0 + 4.0 * i, 0) for i in range(6)},
    **{k: (x, y, 0) for k, (x, y) in HOLES.items()},
}

# reference-text positions (absolute, horizontal) where the footprint default collides or falls off the board
REF_AT = {"U1": (145.84, 188.0), "U2": (155.81, 126.66), "J2": (171.8, 180.5), "C6": (178.3, 170.0)}

SOLID_GND_PADS = [("U2", "10")]

# hand-placed track stubs (net, layer, width, points): Freerouting can't escape U1 pad 1 (+3V3) from under the
# antenna slot on its own, so lead it out to the open area on the left first
PREROUTE = [("/+3V3", "B.Cu", 0.4, [(134.41, 159.315), (130.5, 159.315), (130.5, 150.0)])]

POWER_NETS = {"/GND": 0.6, "/V_SYS": 0.6, "/VIN_RAW": 0.8, "/SW_A": 0.8, "/SW_B": 0.8, "/+3V3": 0.4}

def outline():
    """Full-width body with only the bottom tab (kit USB end + DC jack reach the bottom wall). The top edge is
    straight at Y0 + NH: the old top tab held no parts."""
    x1, y1 = X0 + W, Y0 + H
    return [(X0, Y0 + NH), (x1, Y0 + NH), (x1, y1 - NH), (x1 - NW, y1 - NH),
            (x1 - NW, y1), (X0 + NW, y1), (X0 + NW, y1 - NH), (X0, y1 - NH)]


def tidy_silk(fp, ref):
    """Keep silkscreen on the board: ref text inside axial/disc bodies (stacked parts), no mounting-hole refs,
    and clip the DC jack's outline at the bottom edge it sits flush against."""
    name = fp.GetFPIDAsString()
    if "R_Axial" in name or "C_Disc" in name:
        pads = list(fp.Pads())
        mid = (pads[0].GetPosition() + pads[1].GetPosition()) / 2
        r = fp.Reference()
        r.SetPosition(pcbnew.VECTOR2I(int(mid.x), int(mid.y)))
        r.SetTextSize(pcbnew.VECTOR2I(mm(1.0), mm(1.0)))
        r.SetTextThickness(mm(0.15))
        r.SetTextAngleDegrees(0)
    if ref.startswith("H"):
        fp.Reference().SetVisible(False)
    if ref in REF_AT:
        fp.Reference().SetPosition(pt(*REF_AT[ref]))
        fp.Reference().SetTextAngleDegrees(0)
    ymax = mm(Y0 + H - 0.5)
    for it in list(fp.GraphicalItems()):
        if it.GetLayer() != pcbnew.F_SilkS or it.GetClass() != "PCB_SHAPE" or it.GetShape() != pcbnew.SHAPE_T_SEGMENT:
            continue
        a, b = it.GetStart(), it.GetEnd()
        if a.y > ymax and b.y > ymax:
            fp.Remove(it)
        elif a.y > ymax:
            it.SetStart(pcbnew.VECTOR2I(a.x, ymax))
        elif b.y > ymax:
            it.SetEnd(pcbnew.VECTOR2I(b.x, ymax))


def build():
    comps, pad_net = netlist(SCH, BUILD)
    strip_board(PCB, BUILD)
    board = pcbnew.LoadBoard(str(PCB))

    # outline, antenna slot, cable-tie holes
    edge_poly(board, outline())
    sx0, sy0, sx1, sy1 = SLOT
    edge_poly(board, [(sx0, sy0), (sx1, sy0), (sx1, sy1), (sx0, sy1)])
    for x, y in TIE_HOLES:
        edge_circle(board, x, y, 3.0)

    nets = add_nets(board, pad_net)
    add_footprints(board, comps, pad_net, nets, PLACE, tidy_silk)

    t = pcbnew.PCB_TEXT(board)
    t.SetText("SaltMon carrier v0.2")
    t.SetPosition(pt(118.0, 150.0))
    t.SetLayer(pcbnew.F_SilkS)
    t.SetTextSize(pcbnew.VECTOR2I(mm(1.2), mm(1.2)))
    board.Add(t)

    add_tracks(board, nets, PREROUTE)
    rules(board, POWER_NETS)
    return board


if __name__ == "__main__":
    board = build()
    if "--no-route" not in sys.argv:
        route(board, BUILD)
        gnd_pour(board, board.FindNet("/GND"), outline(), SOLID_GND_PADS)
    board.Save(str(PCB))
    print("wrote", PCB)

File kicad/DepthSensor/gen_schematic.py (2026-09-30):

#!/usr/bin/env python3
"""Generate the SaltMon carrier schematic (DepthSensor.kicad_sch).

Label-driven: every pin end gets a net label (or a no-connect flag), so the netlist is defined entirely by the
NETS tables below, which mirror docs/pinmap.md and docs/requirements.md §3–§6. Symbols are embedded from the
stock KiCad libraries and kicad/lib/SaltMon.kicad_sym (helpers in kicad/lib/schgen.py).

Run:  python3 kicad/DepthSensor/gen_schematic.py
Check: kicad-cli sch erc kicad/DepthSensor/DepthSensor.kicad_sch
"""
import sys
from pathlib import Path

HERE = Path(__file__).resolve().parent
sys.path.insert(0, str(HERE.parent / "lib"))
from schgen import G, init, note, place, text, write  # noqa: E402

OUT = HERE / "DepthSensor.kicad_sch"
init("DepthSensor", "c60f782c-b422-45cf-a51e-6656e6b8da61", "5a1f0000-5a17-4d0e-8000-000000000000")

# ---------------------------------------------------------------- footprints

FP_R = "Resistor_THT:R_Axial_DIN0207_L6.3mm_D2.5mm_P10.16mm_Horizontal"
FP_C = "Capacitor_THT:C_Disc_D5.0mm_W2.5mm_P5.00mm"
FP_TP = "TestPoint:TestPoint_THTPad_1.5x1.5mm_Drill0.7mm"

# ---------------------------------------------------------------- 1. power input

note("1. POWER IN  (req §4)", 20.32, 25.4)
text("J1 center-positive 5 V -> F1 PTC -> lid switch (via J3 pins 11-14) -> D1 -> V_SYS (~4.6 V) -> kit 5V pin.\n"
     "Bench without lid: jumper plug on J3 shorting pins 11-14.", 20.32, 27.94)
place("Connector:Barrel_Jack_Switch", "J1", "PJ-102AH", G * 10, G * 18,
      {"1": "VIN_RAW", "2": "GND", "3": None}, fp="Connector_BarrelJack:BarrelJack_CUI_PJ-102AH_Horizontal")
place("Device:Polyfuse", "F1", "RXEF075", G * 24, G * 18, {"1": "VIN_RAW", "2": "SW_A"},
      fp="Fuse:Fuse_Bourns_MF-RHT070", fields={"Description": "PTC 0.75 A hold / 1.5 A trip, 5.1 mm radial"})
place("Diode:1N5822", "D1", "1N5822", G * 36, G * 18, {"1": "V_SYS", "2": "SW_B"}, rot=180)
place("Device:D_Zener", "D2", "P6KE6.8A", G * 48, G * 18, {"1": "V_SYS", "2": "GND"}, rot=270,
      fp="Diode_THT:D_DO-15_P10.16mm_Horizontal",
      fields={"Description": "Unidirectional TVS 600 W, 5.8 V standoff (optional)"},
      prop_at={"Reference": (2.54, -1.27), "Value": (2.54, 1.27)})
place("Device:C_Polarized", "C1", "220u 16V", G * 56, G * 18, {"1": "V_SYS", "2": "GND"},
      fp="Capacitor_THT:CP_Radial_D8.0mm_P3.50mm")
place("Device:C", "C3", "100n", G * 64, G * 18, {"1": "V_SYS", "2": "GND"}, fp=FP_C)
place("power:PWR_FLAG", "#FLG01", "PWR_FLAG", G * 72, G * 16, {"1": "V_SYS"})
place("power:PWR_FLAG", "#FLG02", "PWR_FLAG", G * 78, G * 16, {"1": "GND"})

# ---------------------------------------------------------------- 2. MCU

note("2. MCU  ESP32-C6-DevKitM-1 (socketed)", 106.68, 88.9)
text("Strapping/USB/UART0 pins left open: GPIO4/5/8/9/15, 12/13, 16/17.\n"
     "3V3 comes from the kit LDO (feeds the US-100 only).", 106.68, 91.44)
U1 = {"1": "+3V3", "2": None, "3": "LED_CH1", "4": "LED_CH2", "5": None, "6": None, "7": "LED_CH3",
      "8": "LED_CH4", "9": None, "10": "LED_CH5", "11": "LED_CH6", "12": "LED_CH7", "13": "GND", "14": "V_SYS",
      "15": "GND",
      "16": "GND", "17": None, "18": None, "19": "SNS_RX", "20": "SNS_TX", "21": "SPARE_B", "22": "SPARE_A",
      "23": "BTN_N", "24": "LED_CH8", "25": None, "26": None, "27": "GND", "28": None, "29": None, "30": "GND"}
place("SaltMon:ESP32-C6-DevKitM-1", "U1", "ESP32-C6-DevKitM-1", G * 60, G * 50, U1)

# ---------------------------------------------------------------- 3. LED driver

note("3. LED DRIVER  (req §5.1)", 213.36, 25.4)
text("GPIO HIGH = LED on. RN1 pull-downs keep LEDs off through reset/boot.\n"
     "R1-R8 on the carrier; LED cathodes return on J3 pins 15/16.", 213.36, 27.94)
U2 = {str(i): f"LED_CH{i}" for i in range(1, 9)}
U2.update({str(19 - i): f"DRV_O{i}" for i in range(1, 9)})
U2.update({"9": "V_SYS", "10": "GND"})
place("Transistor_Array:TBD62783A", "U2", "TBD62783APG", G * 96, G * 28, U2,
      fp="Package_DIP:DIP-18_W7.62mm_Socket")
place("Device:C", "C2", "100n", G * 108, G * 22, {"1": "V_SYS", "2": "GND"}, fp=FP_C)
RN = {"1": "GND"}
RN.update({str(i + 1): f"LED_CH{i}" for i in range(1, 9)})
place("Device:R_Network08", "RN1", "100k", G * 96, G * 46, RN, fp="Resistor_THT:R_Array_SIP9")
LED_R = ["180", "300", "300", "300", "470", "470", "180", "300"]
LED_NAME = ["Green", "Yellow", "Orange", "Red", "Blue", "Purple", "Bi-Green", "Bi-Red"]
for i in range(8):
    place("Device:R", f"R{i + 1}", LED_R[i], G * (118 + 4 * i), G * 22,
          {"1": f"DRV_O{i + 1}", "2": f"LED_A{i + 1}"}, fp=FP_R, fields={"Description": LED_NAME[i]})
place("Device:R", "R9", "1k5", G * 150, G * 22, {"1": "V_SYS", "2": "LED_PWR"}, fp=FP_R,
      fields={"Description": "White power LED, ~1 mA"})

# ---------------------------------------------------------------- 4. lid panel

note("4. LID PANEL  J_PANEL (req §5.2)", 299.72, 88.9)
text("Shrouded 2x8, 16-way ribbon ~20 cm to the hand-wired lid.\nSW_A/SW_B each use two conductors.", 299.72, 91.44)
JP = {str(i): f"LED_A{i}" for i in range(1, 9)}
JP.update({"9": "LED_PWR", "10": "BTN_N", "11": "SW_A", "12": "SW_A", "13": "SW_B", "14": "SW_B",
           "15": "GND", "16": "GND"})
place("Connector_Generic:Conn_02x08_Odd_Even", "J3", "J_PANEL", G * 134, G * 48, JP,
      fp="Connector_IDC:IDC-Header_2x08_P2.54mm_Vertical")

# ---------------------------------------------------------------- 5. sensor

note("5. SENSOR  US-100 (UART mode)  J_SNS", 20.32, 185.42)
text("100 R + 1 nF on each data line (RC 100 ns). 6-way ribbon ~1.2 m; far end 1x5 Dupont.", 20.32, 187.96)
place("Device:R", "R11", "100", G * 12, G * 82, {"1": "SNS_TX", "2": "SNS_TX_C"}, fp=FP_R)
place("Device:R", "R12", "100", G * 20, G * 82, {"1": "SNS_RX", "2": "SNS_RX_C"}, fp=FP_R)
place("Device:C", "C7", "1n", G * 28, G * 82, {"1": "SNS_TX_C", "2": "GND"}, fp=FP_C)
place("Device:C", "C8", "1n", G * 36, G * 82, {"1": "SNS_RX_C", "2": "GND"}, fp=FP_C)
place("Device:C_Polarized", "C6", "10u", G * 44, G * 82, {"1": "+3V3", "2": "GND"},
      fp="Capacitor_THT:CP_Radial_D5.0mm_P2.00mm")
place("Device:C", "C4", "100n", G * 52, G * 82, {"1": "+3V3", "2": "GND"}, fp=FP_C)
place("Connector_Generic:Conn_02x03_Odd_Even", "J2", "J_SNS", G * 68, G * 82,
      {"1": "+3V3", "2": "SNS_TX_C", "3": "SNS_RX_C", "4": "GND", "5": "GND", "6": None},
      fp="Connector_IDC:IDC-Header_2x03_P2.54mm_Vertical")

# ---------------------------------------------------------------- 6. button, spare, test, mech
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

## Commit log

2026-09-28 SaltMon carrier: requirements, pin map, integration contract, KiCad schematic and routed PCB
    - docs: requirements v0.7, pin map, SNS integration contract, pick list, kit datasheets
    - kicad/lib: ESP32-C6-DevKitM-1 symbol + socketed footprint (gen_devkit.py)
    - kicad/DepthSensor: generated schematic (gen_schematic.py, ERC clean) and PCB
    placed, Freerouting-routed and GND-poured (gen_pcb.py, DRC clean), Gerbers
    - Freerouting jar is not committed; gen_pcb.py says where to get it
    [DepthSensor-B_Cu.gbr, DepthSensor-B_Mask.gbr, DepthSensor-B_Paste.gbr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]
2026-09-30 Add lid panel PCB rev 0.1, lid pick list; carrier rev 0.2 without top tab
    - kicad/LidPanel: passive lid board (8 flat-top 5 mm LEDs, J1 right-angle 2x8,
    pads for the panel switch and button), routed, with a 1:1 lid drilling
    template on User.Drawings
    - kicad/lib: shared schgen/pcbgen helpers used by both boards
    - Carrier rev 0.2: top tab removed (80.5 x 92 mm), rerouted
    - docs: lid-pick-list.md with DigiKey part numbers; pick list, requirements
    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
    [DepthSensor.kicad_pcb, LidPanel.kicad_pcb, LidPanel.kicad_sch]
